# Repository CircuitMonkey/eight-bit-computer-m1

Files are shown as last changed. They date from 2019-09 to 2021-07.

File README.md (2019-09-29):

# eight-bit-computer-m1
Surface Mount Technology (SMT) implementation of Ben Eater's 8-bit Computer

The "M1" project is a Surface Mount Technology (SMT) implementation of [Ben Eater's 8-bit computer project](https://eater.net/8bit) as a compact and modular kit designed in Autodesk Eagle.   If you don't want to mess with SMT or Eagle, Ben has made his kit PCB available in KiCAD already,  or consider purchasing his kit.

For this implementation, I have re-entered all of the design files and created new suirface-mount library components into Eagle, by hand.  Therefore there are likely to be a few errors or unexpected differences encountered. Your feedback would be much appreciated.

Circuit Monkey is not affiliated with Ben Eater. However, if you appreciate this or Ben's project, please consider supporting Ben's work directly and financially using any one of the methods listed on his website.

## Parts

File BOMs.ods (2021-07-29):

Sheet: center-plane-rev-a
Part | Value | Package | Description | Price | Have | Buy
FAB | PCB Fab |  |  | $15.00
RL1 | 1K | 0603-RES | Resistor | $0.05
RL2 | 1K | 0603-RES | Resistor | $0.05
R0 | 1K | 0603-RES | Resistor | $0.05
R1 | 1K | 0603-RES | Resistor | $0.05
R2 | 1K | 0603-RES | Resistor | $0.05
R3 | 1K | 0603-RES | Resistor | $0.05
R4 | 1K | 0603-RES | Resistor | $0.05
R5 | 1K | 0603-RES | Resistor | $0.05
R6 | 1K | 0603-RES | Resistor | $0.05
R7 | 1K | 0603-RES | Resistor | $0.05
R8 | 10K | 0603-RES | Resistor | $0.05
R9 | 10K | 0603-RES | Resistor | $0.05
R10 | 10K | 0603-RES | Resistor | $0.05
R11 | 10K | 0603-RES | Resistor | $0.05
R12 | 10K | 0603-RES | Resistor | $0.05
R13 | 10K | 0603-RES | Resistor | $0.05
R14 | 10K | 0603-RES | Resistor | $0.05
R15 | 10K | 0603-RES | Resistor | $0.05
0 | BLUE | SMD_0603 | LED SMT | $0.15 |  |  | Wurth | 150060BS75000
1 | BLUE | SMD_0603 | LED SMT | $0.15 |  |  | Wurth | 150060BS75000
2 | BLUE | SMD_0603 | LED SMT | $0.15 |  |  | Wurth | 150060BS75000
3 | BLUE | SMD_0603 | LED SMT | $0.15 |  |  | Wurth | 150060BS75000
4 | BLUE | SMD_0603 | LED SMT | $0.15 |  |  | Wurth | 150060BS75000
5 | BLUE | SMD_0603 | LED SMT | $0.15 |  |  | Wurth | 150060BS75000
6 | BLUE | SMD_0603 | LED SMT | $0.15 |  |  | Wurth | 150060BS75000
7 | BLUE | SMD_0603 | LED SMT | $0.15 |  |  | Wurth | 150060BS75000
PLD1 | BLUE | SMD_0603 | LED SMT | $0.15 |  |  | Wurth | 150060BS75000
PLD2 | BLUE | SMD_0603 | LED SMT | $0.15 |  |  | Wurth | 150060BS75000
ALU | M1-ALU-BUS | ALU | ALU – PCB
CLK | M1-CLOCK-BUS | CLOCK | Clock - Bus Side – PCB | $7.57
CTL | M1-CONTROL-BUS | CONTROL | Control Logic - PCB
RAM | M1-RAM-BUS | M1-RAM-BUS | M1 - RAM - Bus Side
MAR | M1-MAR-BUS | MAR | MAR – PCB
OUT | M1-REG-OUTPUT-BUS | OUTPUT | Output – PCB | $19.55
PC | M1-PROG-COUNTER-BUS | PC | PC -PCB | $6.30
A | M1-REG-A-BUS | REG-A | Register A – PCB | $9.45
B | M1-REG-B-BUS | REG-B | Register B – PCB | $9.21
IR | M1-REG-INSTR-BUS | REG-I | Register Inst. - PCB | $9.45
 |  |  | Parts Total: | $78.93

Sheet: output-rev-a
Part | Value | Package | Description | Price | Have | Buy | MFR | MPN
C2 | 0.1uF | 0603-CAP | Capacitor CAP | $0.10
C3 | 0.1uF | 0603-CAP | Capacitor CAP | $0.10
C4 | 0.1uF | 0603-CAP | Capacitor CAP | $0.10
C5 | 0.1uF | 0603-CAP | Capacitor CAP | $0.10
C6 | 0.1uF | 0603-CAP | Capacitor CAP | $0.10
CCT | 0.01uF | 0603-CAP | Capacitor CAP | $0.10
CTH | 0.01uF | 0603-CAP | Capacitor CAP | $0.10
R1 | 100K | 0603-RES | Resistor | $0.05
R2 | 1K | 0603-RES | Resistor | $0.05
R3 | 1K | 0603-RES | Resistor | $0.05
R4 | 1K | 0603-RES | Resistor | $0.05
R5 | 1K | 0603-RES | Resistor | $0.05
R6 | 1K | 0603-RES | Resistor | $0.05
R7 | 1K | 0603-RES | Resistor | $0.05
R8 | 1K | 0603-RES | Resistor | $0.05
R9 | 1K | 0603-RES | Resistor | $0.05
R10 | 1K | 0603-RES | Resistor | $0.05
LED0 | BLUE | AVAGO-HDSM-283B-7SEG | Seven Segment LED Display | $2.70 |  |  | Avago | HDSM-283B
LED1 | BLUE | AVAGO-HDSM-283B-7SEG | Seven Segment LED Display | $2.70 |  |  | Avago | HDSM-283B
LED2 | BLUE | AVAGO-HDSM-283B-7SEG | Seven Segment LED Display | $2.70 |  |  | Avago | HDSM-283B
LED3 | BLUE | AVAGO-HDSM-283B-7SEG | Seven Segment LED Display | $2.70 |  |  | Avago | HDSM-283B
U1 | 555 | SOP08 | 555 Timer Chip | $0.50 |  |  | TI | NE555PSR
U2 | 74HCT109D | SO16 | Dual J-K Flip Flop Pos. Edge | $0.50 |  |  |  | 74HCT109D
U3 | 74LS139AD | SO16 | Dual 2-line to 4-line Decoder/Demux | $0.75 |  |  |  | 74LS139AD
U4 | 74LS273NS | SO20 | Octal D-type Flip Flop | $0.85 |  |  |  | 74LS273NS
U5 | 74LS08 | SOP14 | Quad AND Gate | $0.55 |  |  |  | 74LS08D
U6 | 28C64 | SO28 | EEPROM 8K x 8 | $4.40 |  |  | Microchip | AT28C64B-15SU
 |  |  | Parts Total: | $19.55

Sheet: clock-rev-a
M1 – Clock |  |  |  | Rev.A
Part | Value | Package | Description | Price | HAVE | BUY | MFR | MPN | MPN2
FAB | Clock PCB |  | PCB | $2.00
C1 | 0.01uF | 0603-CAP | Capacitor | $0.10
C2 | 1.0uF | 0603-CAP | Capacitor | $0.20
C3 | 0.01uF | 0603-CAP | Capacitor | $0.10
C4 | 0.01uF | 0603-CAP | Capacitor | $0.10
C5 | 0.01uF | 0603-CAP | Capacitor | $0.10
CU4 | 0.01uF | 0603-CAP | Capacitor | $0.10
CU5 | 0.01uF | 0603-CAP | Capacitor | $0.10
R1 | 1K | 0603-RES | Resistor | $0.05
R2 | 1K | 0603-RES | Resistor | $0.05
R3 | 1K | 0603-RES | Resistor | $0.05
R4 | 1K | 0603-RES | Resistor | $0.05
R5 | 1K | 0603-RES | Resistor | $0.05
R6 | 1K | 0603-RES | Resistor | $0.05
R7 | 1K | 0603-RES | Resistor | $0.05
.CLK. | BLUE | SMD_0603 | LED SMT | $0.15
F | 1M | TRIM_BOURNS_TC33X | Potentiometer | $0.27 |  | Mouser | Bourns | TC33X-2-105
MODE |  | CK_JS102011JCQN | Slide Switch - SPDT | $0.70 |  |  | CK Switch | JS102011JCQN
STEP | MOM (OFF)-ON | SWITCH-0635-2P-SMD | Tactile Push Switch | $0.70 |  |  | CK Switch | PTS635S*SMTR | Pololu #1400
U1 | 555 | SOP08 | Timer Chip | $0.30 |  | Mouser | TI | NE555PSR
U2 | 555 | SOP08 | Timer Chip | $0.30 |  | Mouser | TI | NE555PSR
U3 | 555 | SOP08 | Timer Chip | $0.30 |  | Mouser | TI | NE555PSR
U4 | 74LS08 | SOP14 | 7408 Quad AND | $0.55 |  | Mouser |  | 74LS08D
U5 | 74LS32 | SOP14 | 7432 Quad XOR | $0.55 |  | Mouser |  | 74LS32D
U6 | 74LS04 | SOP14 | Hex Inverter | $0.60 |  | Mouser |  | 74LS04D
 |  |  | Parts Total: | $7.57

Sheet: register-a
M1-Register-A
Part | Value | Device | Package | Description | Cost | Have | Buy
FAB |  |  |  |  | $3.50
C1 | 0.1uF | CAPACITOR0603 | 0603-CAP | Capacitor CAP | $0.10
C2 | 0.1uF | CAPACITOR0603 | 0603-CAP | Capacitor CAP | $0.10
C3 | 0.1uF | CAPACITOR0603 | 0603-CAP | Capacitor CAP | $0.10
R0 | 1K | RESISTOR0603 | 0603-RES | Resistor | $0.05
R1 | 1K | RESISTOR0603 | 0603-RES | Resistor | $0.05
R2 | 1K | RESISTOR0603 | 0603-RES | Resistor | $0.05
R3 | 1K | RESISTOR0603 | 0603-RES | Resistor | $0.05
R4 | 1K | RESISTOR0603 | 0603-RES | Resistor | $0.05
R5 | 1K | RESISTOR0603 | 0603-RES | Resistor | $0.05
R6 | 1K | RESISTOR0603 | 0603-RES | Resistor | $0.05
R7 | 1K | RESISTOR0603 | 0603-RES | Resistor | $0.05
D.0 | BLUE | SMT0603 | SMD_0603 | LED SMT | $0.15
D.1 | BLUE | SMT0603 | SMD_0603 | LED SMT | $0.15
D.2 | BLUE | SMT0603 | SMD_0603 | LED SMT | $0.15
D.3 | BLUE | SMT0603 | SMD_0603 | LED SMT | $0.15
D.4 | BLUE | SMT0603 | SMD_0603 | LED SMT | $0.15
D.5 | BLUE | SMT0603 | SMD_0603 | LED SMT | $0.15
D.6 | BLUE | SMT0603 | SMD_0603 | LED SMT | $0.15
D.7 | BLUE | SMT0603 | SMD_0603 | LED SMT | $0.15
U1 | 74LS245NS | 74LS245NS | SO20 | 74245 Octal Transceiver | $0.95
U2 | 74LS173AD | 74LS173AD | SO16 | 74*173 Logic | $1.55
U3 | 74LS173AD | 74LS173AD | SO16 | 74*173 Logic | $1.55
 |  |  |  | Parts Total: | $9.45

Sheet: register-b
M1-Register-B
Part | Value | Device | Package | Description | Cost | Have | Buy
FAB |  |  |  | PCB Fab | $3.50
C1 | 0.1uF | CAPACITOR0603 | 0603-CAP | Capacitor CAP | $0.10
C2 | 0.1uF | CAPACITOR0603 | 0603-CAP | Capacitor CAP | $0.10
C3 | 0.1uF | CAPACITOR0603 | 0603-CAP | Capacitor CAP | $0.10
R0 | 1K | RESISTOR0603 | 0603-RES | Resistor | $0.05
R1 | 1K | RESISTOR0603 | 0603-RES | Resistor | $0.05
R2 | 1K | RESISTOR0603 | 0603-RES | Resistor | $0.05
R3 | 1K | RESISTOR0603 | 0603-RES | Resistor | $0.05
R4 | 1K | RESISTOR0603 | 0603-RES | Resistor | $0.05
R5 | 1K | RESISTOR0603 | 0603-RES | Resistor | $0.05
R6 | 1K | RESISTOR0603 | 0603-RES | Resistor | $0.05
R7 | 1K | RESISTOR0603 | 0603-RES | Resistor | $0.05
D.0 | BLUE | SMT0603 | SMD_0603 | LED SMT | $0.12
D.1 | BLUE | SMT0603 | SMD_0603 | LED SMT | $0.12
D.2 | BLUE | SMT0603 | SMD_0603 | LED SMT | $0.12
D.3 | BLUE | SMT0603 | SMD_0603 | LED SMT | $0.12
D.4 | BLUE | SMT0603 | SMD_0603 | LED SMT | $0.12
D.5 | BLUE | SMT0603 | SMD_0603 | LED SMT | $0.12
D.6 | BLUE | SMT0603 | SMD_0603 | LED SMT | $0.12
D.7 | BLUE | SMT0603 | SMD_0603 | LED SMT | $0.12
U1 | 74LS245NS | 74LS245NS | SO20 | 74245 Octal Transceiver | $0.95
U2 | 74LS173AD | 74LS173AD | SO16 | 74*173 Logic | $1.55
U3 | 74LS173AD | 74LS173AD | SO16 | 74*173 Logic | $1.55
 |  |  |  | Parts Total: | $9.21

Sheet: program-counter
M1-Program-Counter
Part | Value | Device | Package | Description | Cost | Have | Buy
FAB |  |  |  | PCB Fab | $3.50
C1 | 0.1uF | CAPACITOR0603 | 0603-CAP | Capacitor CAP | $0.10
C2 | 0.1uF | CAPACITOR0603 | 0603-CAP | Capacitor CAP | $0.10
R0 | 1K | RESISTOR0603 | 0603-RES | Resistor | $0.05
R1 | 1K | RESISTOR0603 | 0603-RES | Resistor | $0.05
R2 | 1K | RESISTOR0603 | 0603-RES | Resistor | $0.05
R3 | 1K | RESISTOR0603 | 0603-RES | Resistor | $0.05
PC0 | GREEN | SMT0603 | SMD_0603 | LED SMT | $0.15
PC1 | GREEN | SMT0603 | SMD_0603 | LED SMT | $0.15
PC2 | GREEN | SMT0603 | SMD_0603 | LED SMT | $0.15
PC3 | GREEN | SMT0603 | SMD_0603 | LED SMT | $0.15
U1 | 74LS245NS | 74LS245NS | SO20 | 74245 Octal Transceiver | $0.95
U2 | 74LS161AD | 74LS161AD | SO16 | Synchronous 4-bit Counter | $0.85
 |  |  |  | Parts Total: | $6.30

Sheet: register-i
M1-Instruction-Register
Part | Value | Device | Package | Description | Cost | Have | Buy
FAB |  |  |  | PCB FAB | $3.50
C1 |  | CAPACITOR0603 | 0603-CAP | Capacitor CAP | $0.10
C2 |  | CAPACITOR0603 | 0603-CAP | Capacitor CAP | $0.10
C3 |  | CAPACITOR0603 | 0603-CAP | Capacitor CAP | $0.10
R0 | 1K | RESISTOR0603 | 0603-RES | Resistor | $0.05
R1 | 1K | RESISTOR0603 | 0603-RES | Resistor | $0.05
R2 | 1K | RESISTOR0603 | 0603-RES | Resistor | $0.05
R3 | 1K | RESISTOR0603 | 0603-RES | Resistor | $0.05
R4 | 1K | RESISTOR0603 | 0603-RES | Resistor | $0.05
R5 | 1K | RESISTOR0603 | 0603-RES | Resistor | $0.05
R6 | 1K | RESISTOR0603 | 0603-RES | Resistor | $0.05
R7 | 1K | RESISTOR0603 | 0603-RES | Resistor | $0.05
D.0 | BLUE | SMT0603 | SMD_0603 | LED SMT | $0.15
D.1 | BLUE | SMT0603 | SMD_0603 | LED SMT | $0.15
D.2 | BLUE | SMT0603 | SMD_0603 | LED SMT | $0.15
D.3 | BLUE | SMT0603 | SMD_0603 | LED SMT | $0.15
D.4 | BLUE | SMT0603 | SMD_0603 | LED SMT | $0.15
D.5 | BLUE | SMT0603 | SMD_0603 | LED SMT | $0.15
D.6 | BLUE | SMT0603 | SMD_0603 | LED SMT | $0.15
D.7 | BLUE | SMT0603 | SMD_0603 | LED SMT | $0.15
U1 | 74LS245NS | 74LS245NS | SO20 | 74245 Octal Transceiver | $0.95
U2 | 74LS173AD | 74LS173AD | SO16 | 74*173 Logic | $1.55
U3 | 74LS173AD | 74LS173AD | SO16 | 74*173 Logic | $1.55
 |  |  |  | Parts Total: | $9.45

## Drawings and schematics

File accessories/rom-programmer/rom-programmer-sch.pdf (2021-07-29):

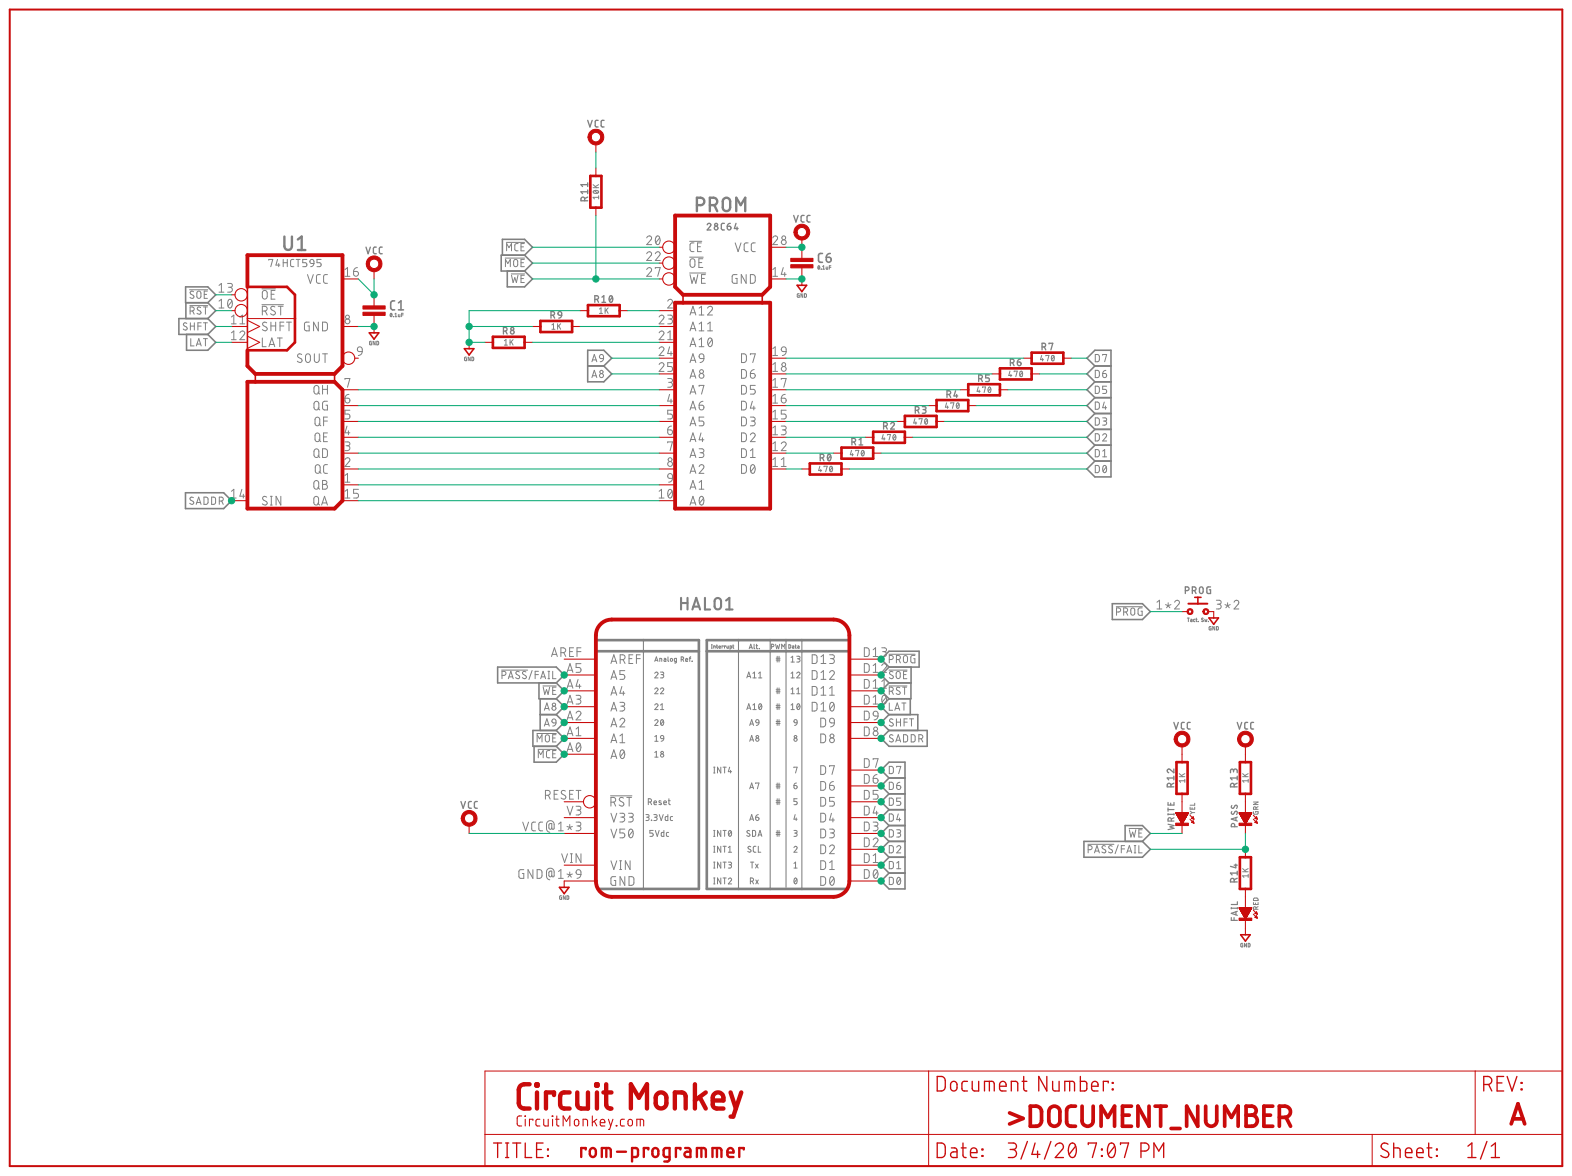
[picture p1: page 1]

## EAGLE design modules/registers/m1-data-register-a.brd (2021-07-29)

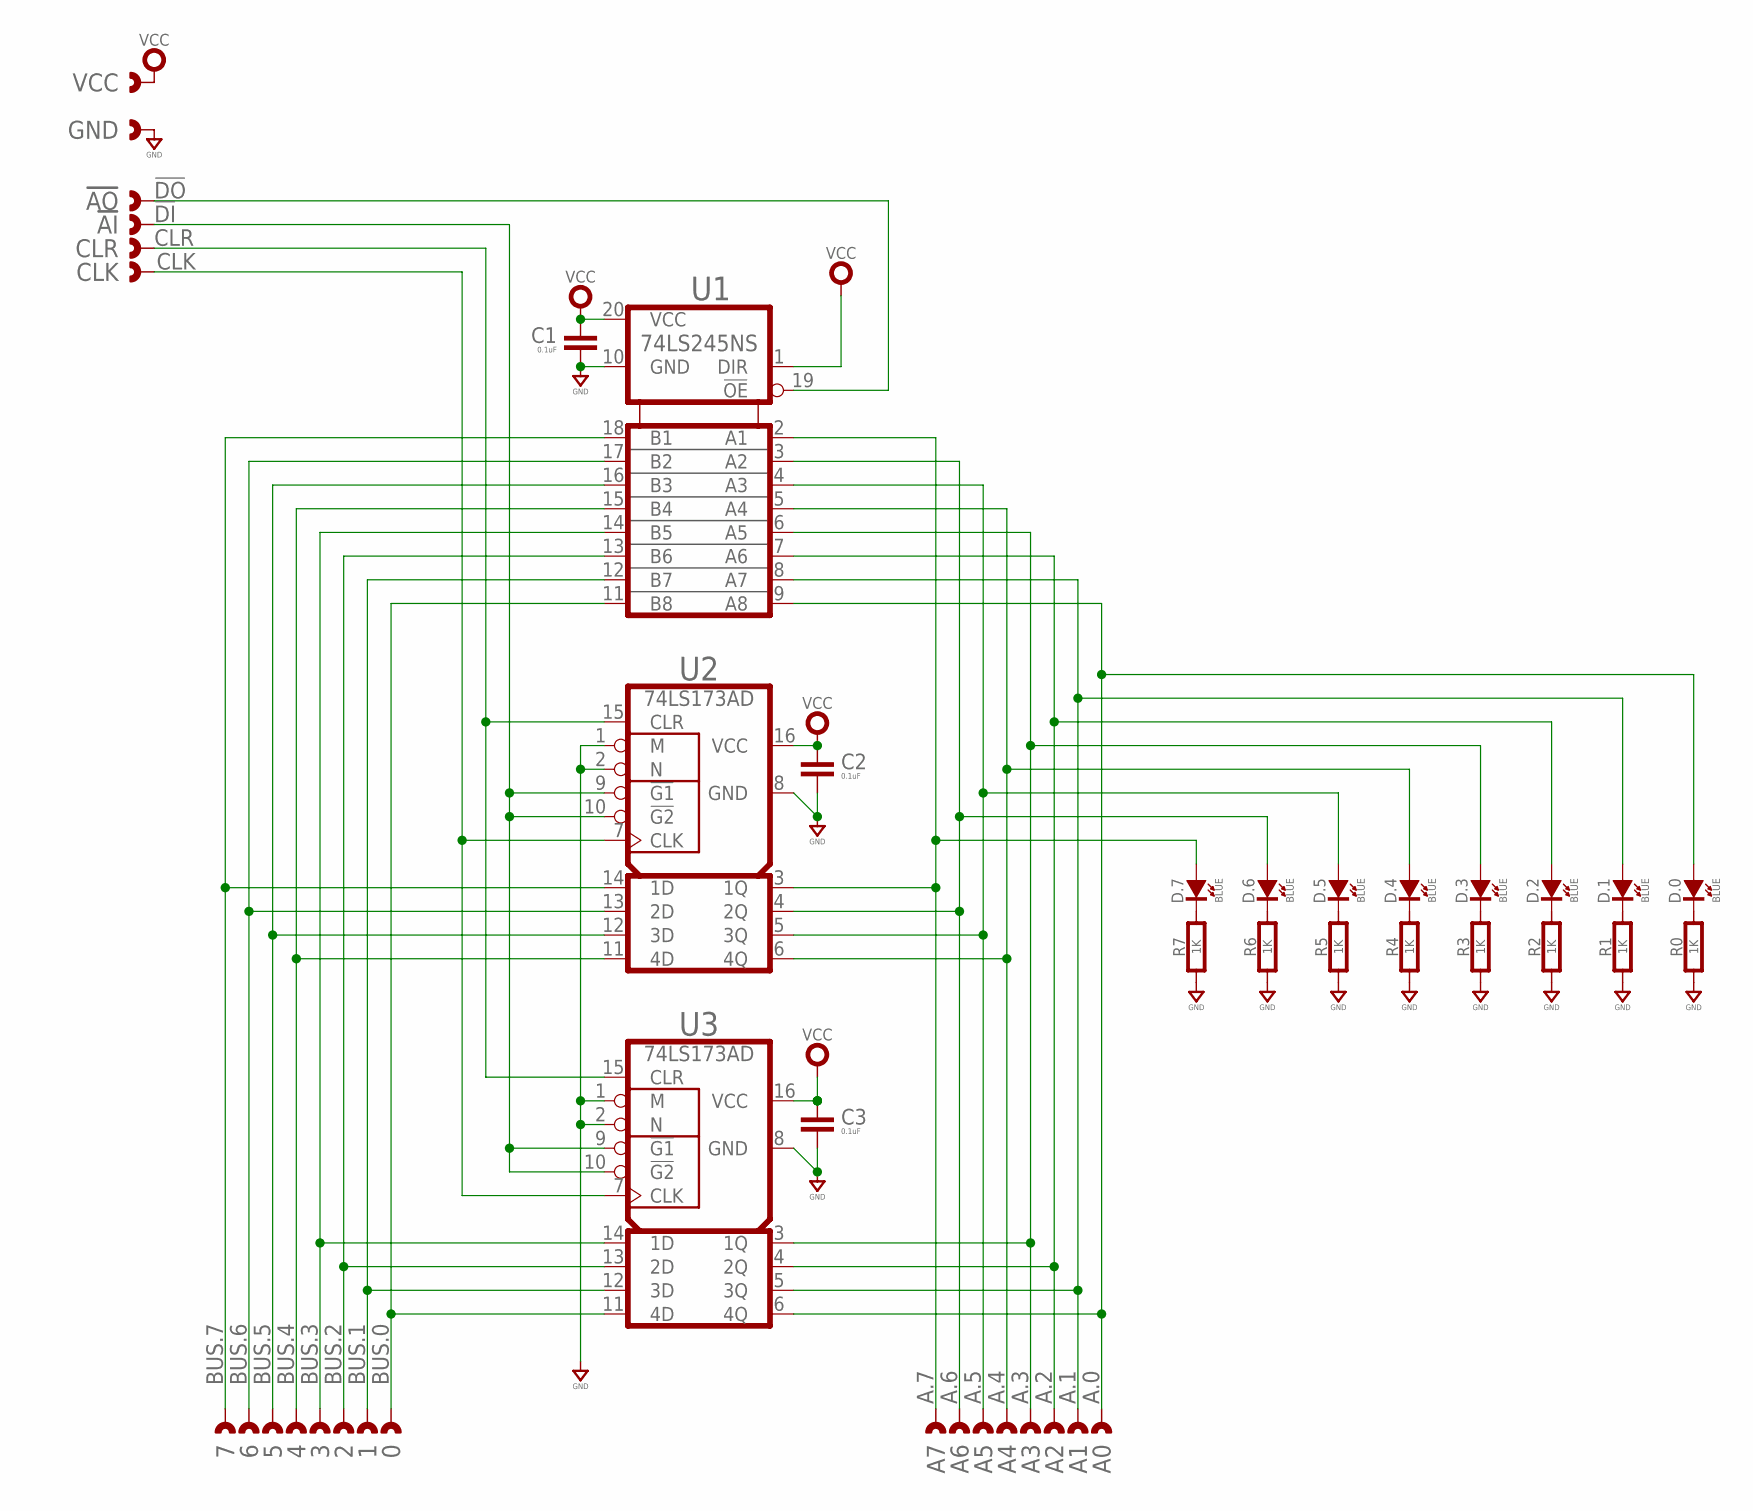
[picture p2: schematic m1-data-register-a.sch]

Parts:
0, 1, 2, 3, 4, 5, 6, 7: CAST-01X1; CAST01-2.54MM
!AI: CAST-01X1; CAST01-2.54MM
!AO: CAST-01X1; CAST01-2.54MM
A0, A1, A2, A3, A4, A5, A6, A7: CAST-01X1; CAST01-2.54MM
C1, C2, C3: 0.1uF; 0603-CAP
CLK: CAST-01X1; CAST01-2.54MM
CLR: CAST-01X1; CAST01-2.54MM
D.0, D.1, D.2, D.3, D.4, D.5, D.6, D.7: BLUE; SMD_0603
GND: CAST-01X1; CAST01-2.54MM
R0, R1, R2, R3, R4, R5, R6, R7: 1K; 0603-RES
U1: 74LS245NS; SO20
U2, U3: 74LS173AD; SO16
VCC: CAST-01X1; CAST01-2.54MM

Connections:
!DI: !AI.1, U2.9 (!G1), U2.10 (!G2), U3.9 (!G1), U3.10 (!G2)
!DO: !AO.1, U1.19 (!OE)
A.0: A0.1, D.0.A, U1.9 (A8), U3.6 (4Q)
A.1: A1.1, D.1.A, U1.8 (A7), U3.5 (3Q)
A.2: A2.1, D.2.A, U1.7 (A6), U3.4 (2Q)
A.3: A3.1, D.3.A, U1.6 (A5), U3.3 (1Q)
A.4: A4.1, D.4.A, U1.5 (A4), U2.6 (4Q)
A.5: A5.1, D.5.A, U1.4 (A3), U2.5 (3Q)
A.6: A6.1, D.6.A, U1.3 (A2), U2.4 (2Q)
A.7: A7.1, D.7.A, U1.2 (A1), U2.3 (1Q)
BUS.0: 0.1, U1.11 (B8), U3.11 (4D)
BUS.1: 1.1, U1.12 (B7), U3.12 (3D)
BUS.2: 2.1, U1.13 (B6), U3.13 (2D)
BUS.3: 3.1, U1.14 (B5), U3.14 (1D)
BUS.4: 4.1, U1.15 (B4), U2.11 (4D)
BUS.5: 5.1, U1.16 (B3), U2.12 (3D)
BUS.6: 6.1, U1.17 (B2), U2.13 (2D)
BUS.7: 7.1, U1.18 (B1), U2.14 (1D)
CLK: CLK.1, U2.7 (CLK), U3.7 (CLK)
CLR: CLR.1, U2.15 (CLR), U3.15 (CLR)
GND: C1.2, C2.2, C3.2, GND.1, R0.1, R1.1, R2.1, R3.1, R4.1, R5.1, R6.1, R7.1, U1.10 (GND), U2.1 (M), U2.2 (N), U2.8 (GND), U3.1 (M), U3.2 (N), U3.8 (GND)
unnamed: D.0.K (C), R0.2
unnamed: D.1.K (C), R1.2
unnamed: D.2.K (C), R2.2
unnamed: D.3.K (C), R3.2
unnamed: D.4.K (C), R4.2
unnamed: D.5.K (C), R5.2
unnamed: D.6.K (C), R6.2
unnamed: D.7.K (C), R7.2
VCC: C1.1, C2.1, C3.1, U1.1 (DIR), U1.20 (VCC), U2.16 (VCC), U3.16 (VCC), VCC.1

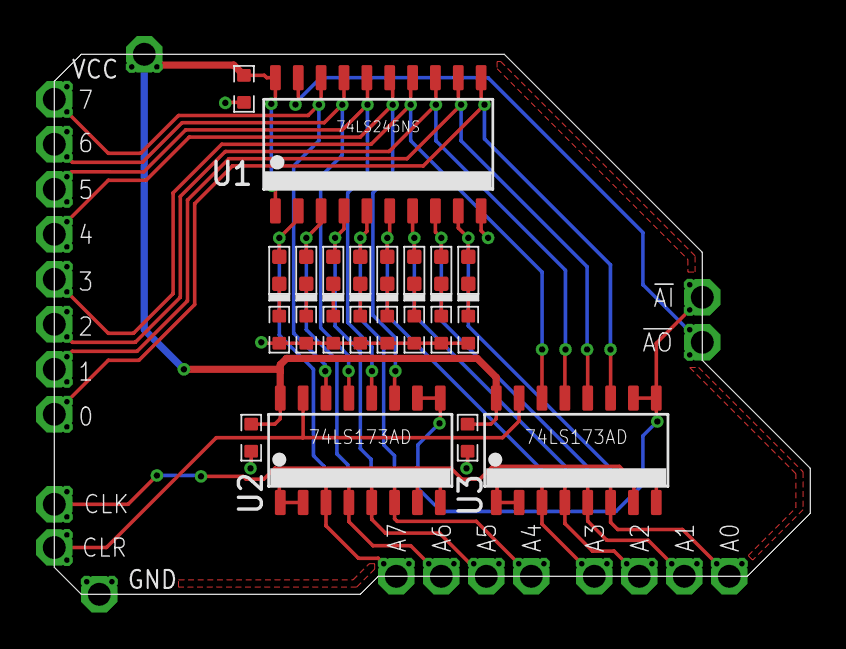
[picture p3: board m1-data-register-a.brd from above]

Board: 2 copper layers, 42.0 x 30.0 mm, 44 parts (0 on the bottom side), 30 nets.

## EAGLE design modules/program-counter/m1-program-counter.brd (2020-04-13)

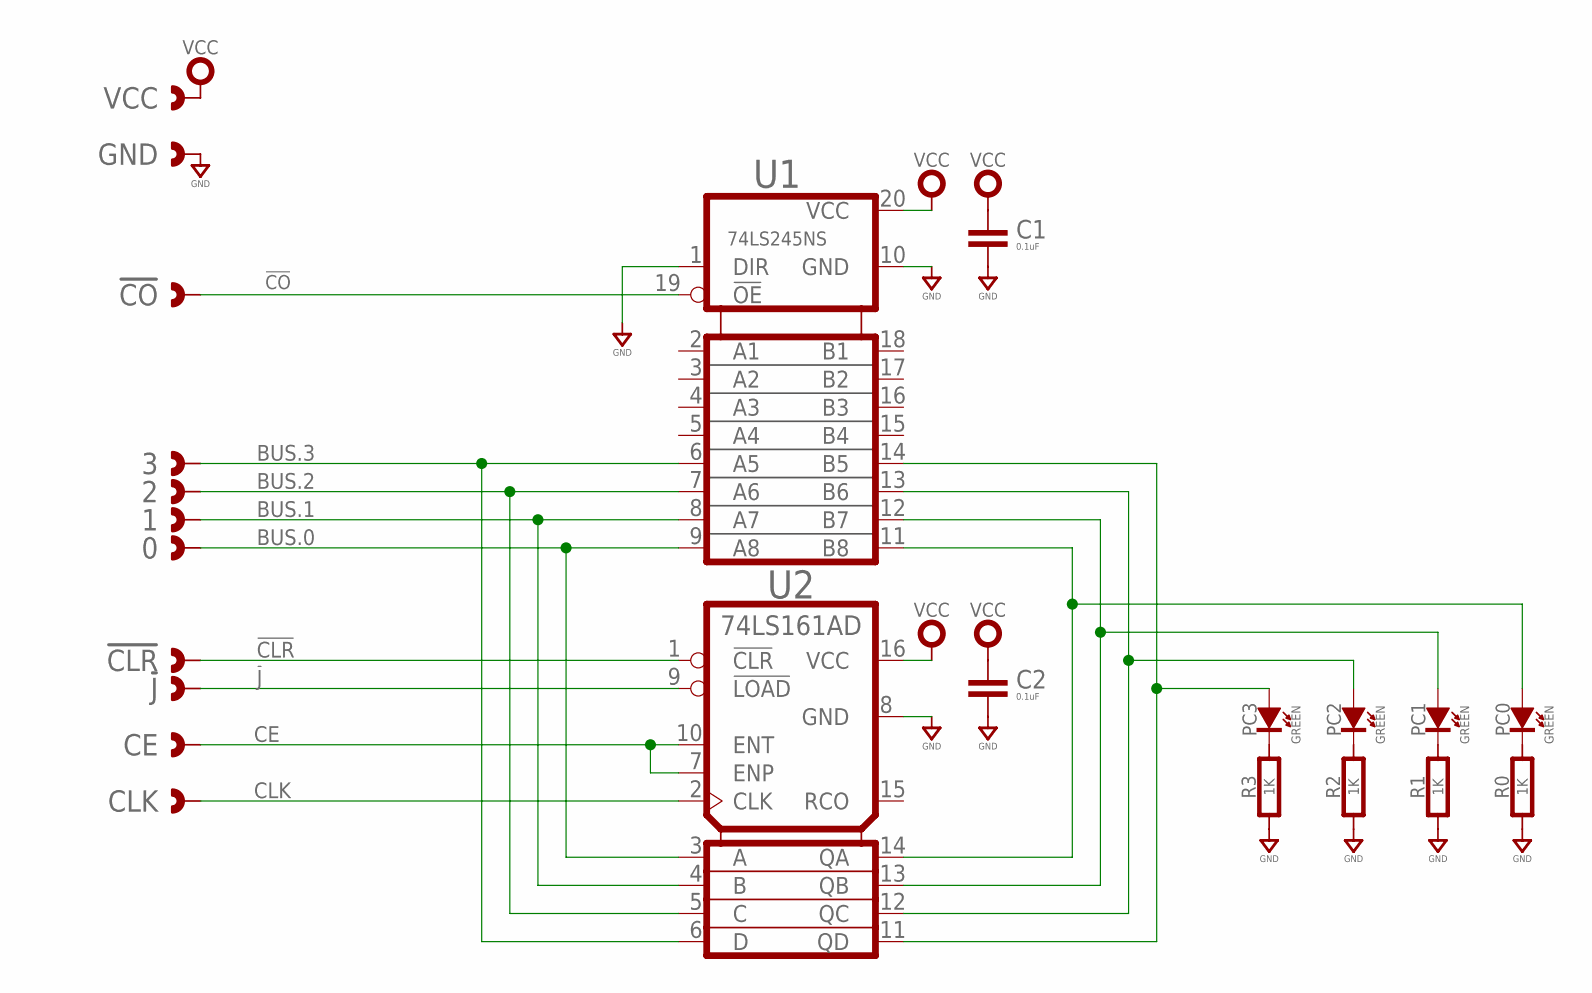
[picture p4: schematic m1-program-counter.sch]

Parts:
0, 1, 2, 3: CAST-01X1; CAST01-2.54MM
!CLR: CAST-01X1; CAST01-2.54MM
!CO: CAST-01X1; CAST01-2.54MM
!J: CAST-01X1; CAST01-2.54MM
C1, C2: 0.1uF; 0603-CAP
CE: CAST-01X1; CAST01-2.54MM
CLK: CAST-01X1; CAST01-2.54MM
GND: CAST-01X1; CAST01-2.54MM
PC0, PC1, PC2, PC3: GREEN; SMD_0603
R0, R1, R2, R3: 1K; 0603-RES
U1: 74LS245NS; SO20
U2: 74LS161AD; SO16
VCC: CAST-01X1; CAST01-2.54MM

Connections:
!CLR: !CLR.1, U2.1 (!CLR)
!CO: !CO.1, U1.19 (!OE)
!J: !J.1, U2.9 (!LOAD)
BUS.0: 0.1, U1.9 (A8), U2.3 (A)
BUS.1: 1.1, U1.8 (A7), U2.4 (B)
BUS.2: 2.1, U1.7 (A6), U2.5 (C)
BUS.3: 3.1, U1.6 (A5), U2.6 (D)
CE: CE.1, U2.7 (ENP), U2.10 (ENT)
CLK: CLK.1, U2.2 (CLK)
GND: C1.2, C2.2, GND.1, R0.1, R1.1, R2.1, R3.1, U1.1 (DIR), U1.10 (GND), U2.8 (GND)
unnamed: PC0.A, U1.11 (B8), U2.14 (QA)
unnamed: PC1.A, U1.12 (B7), U2.13 (QB)
unnamed: PC2.A, U1.13 (B6), U2.12 (QC)
unnamed: PC3.A, U1.14 (B5), U2.11 (QD)
unnamed: PC0.K (C), R0.2
unnamed: PC1.K (C), R1.2
unnamed: PC2.K (C), R2.2
unnamed: PC3.K (C), R3.2
VCC: C1.1, C2.1, U1.20 (VCC), U2.16 (VCC), VCC.1

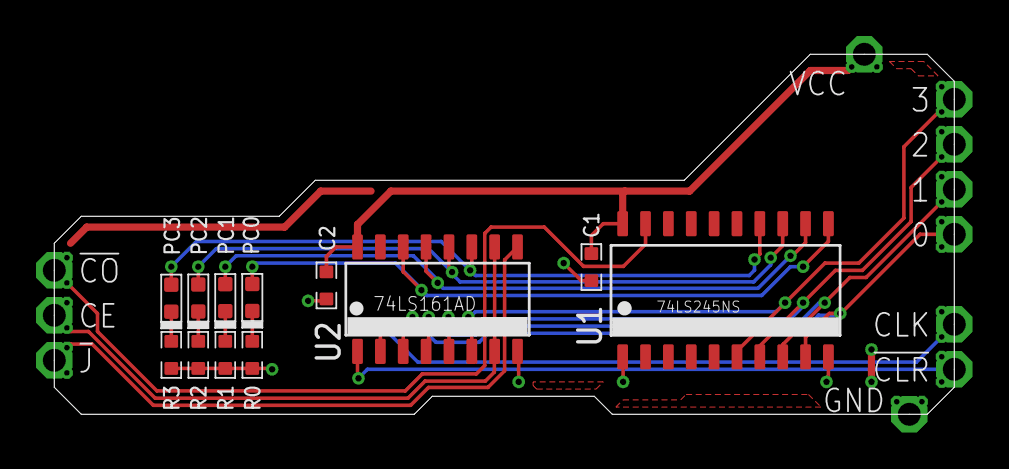
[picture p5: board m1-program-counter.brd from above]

Board: 2 copper layers, 50.0 x 20.0 mm, 23 parts (0 on the bottom side), 19 nets.

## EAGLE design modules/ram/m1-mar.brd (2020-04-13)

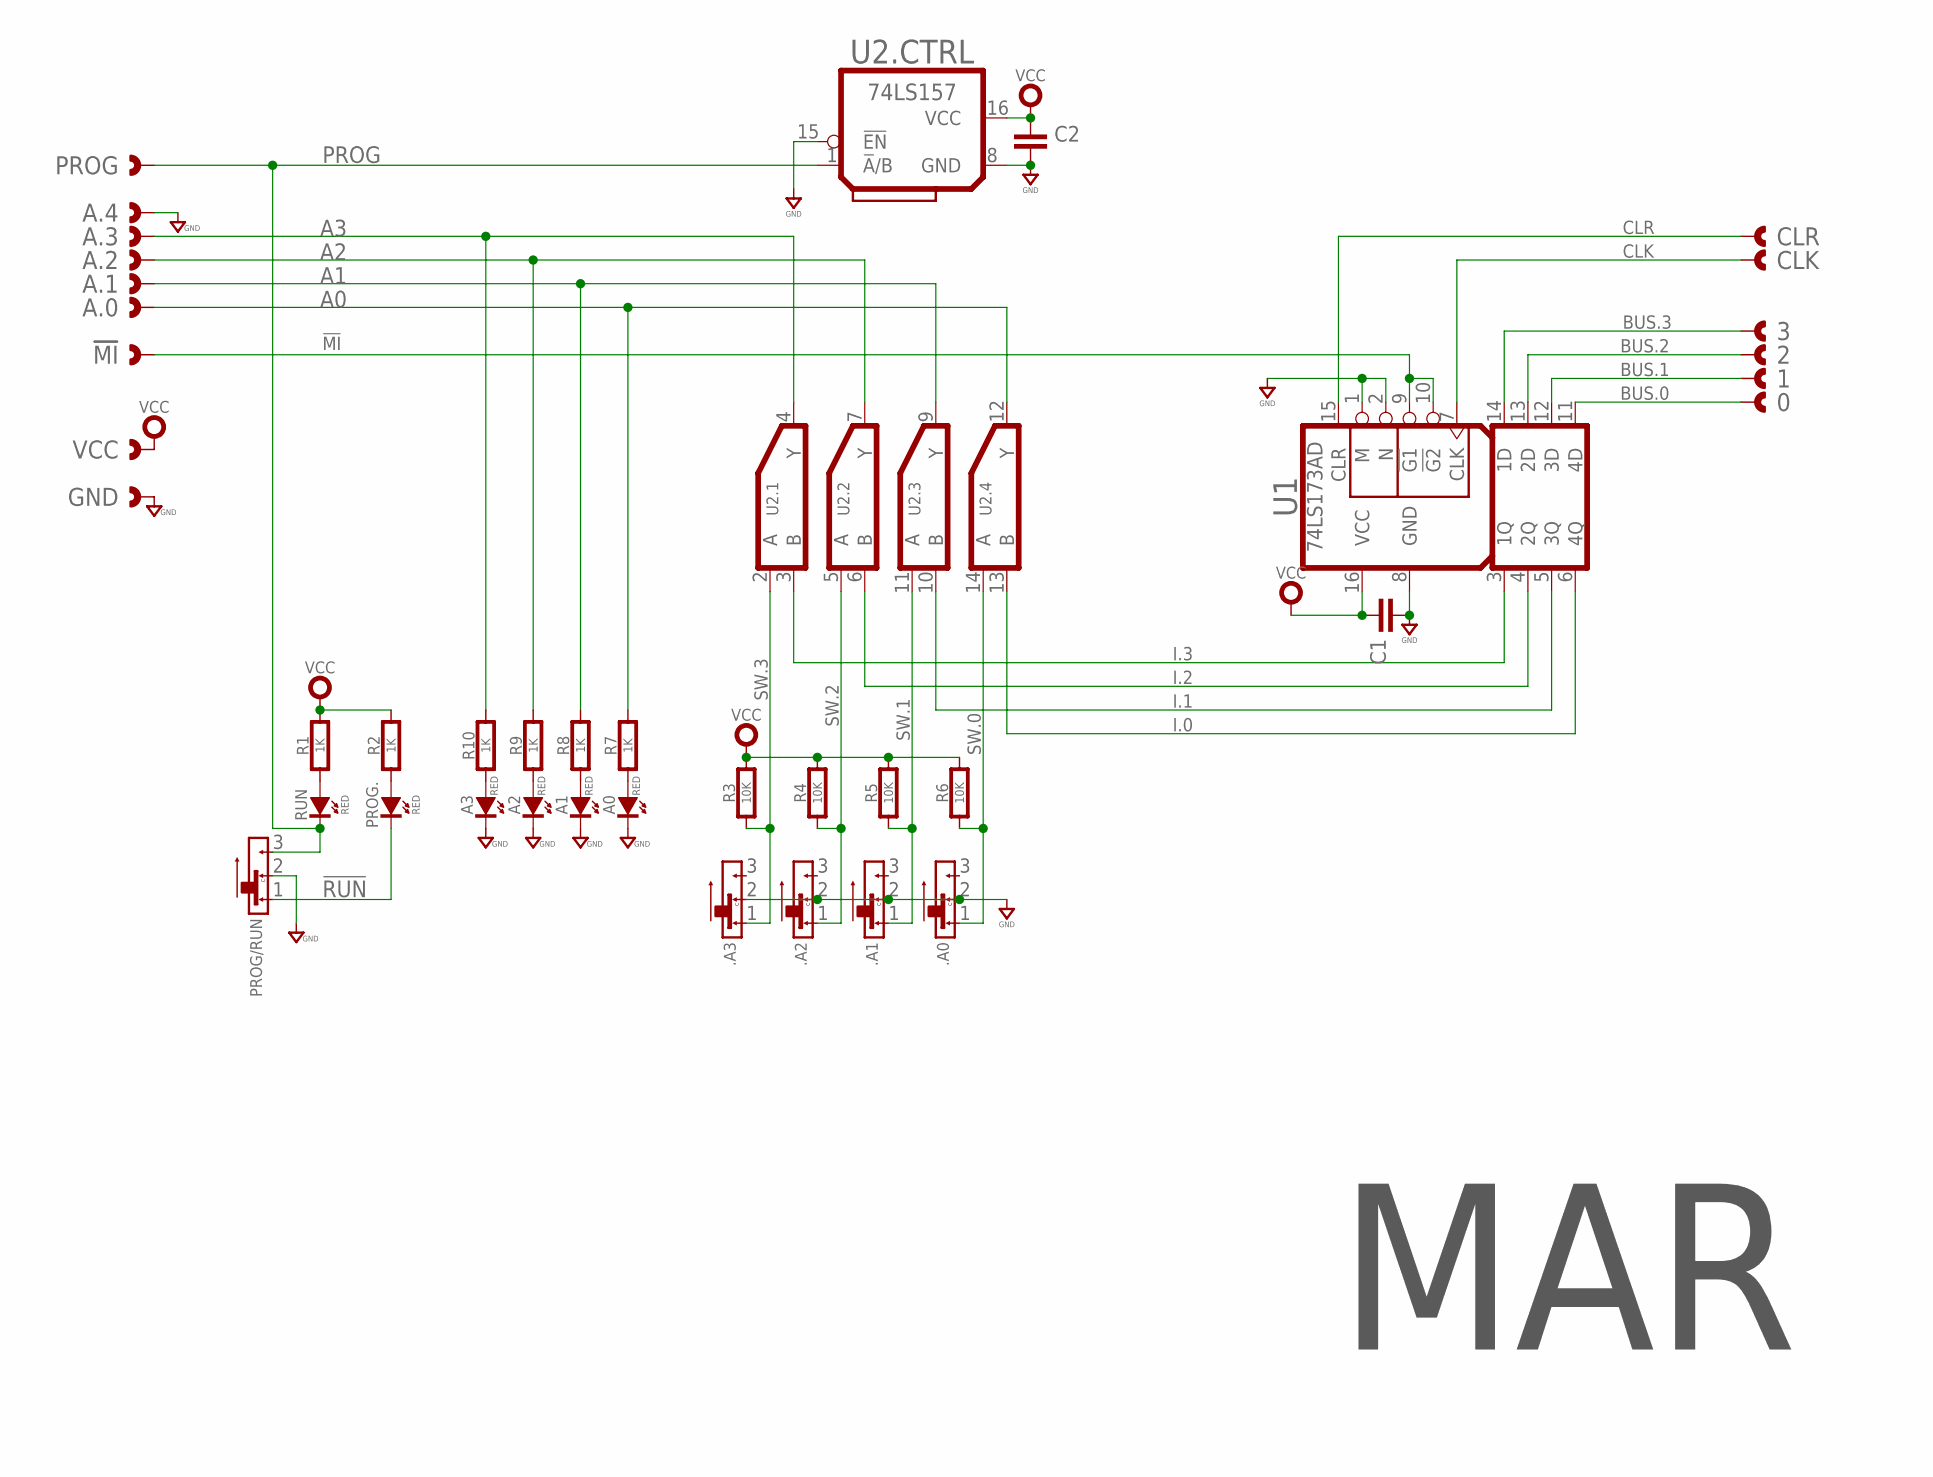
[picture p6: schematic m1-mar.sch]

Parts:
0, 1, 2, 3: CAST-01X1; CAST01-2.54MM
!MI: CAST-01X1; CAST01-2.54MM
.A0, .A1, .A2, .A3: SLIDE-SPDTJS102011JCQN; CK_JS102011JCQN
A0, A1, A2, A3: RED; SMD_0603
A.0, A.1, A.2, A.3, A.4: CAST-01X1; CAST01-2.54MM
C1, C2: CAPACITOR0603; 0603-CAP
CLK: CAST-01X1; CAST01-2.54MM
CLR: CAST-01X1; CAST01-2.54MM
GND: CAST-01X1; CAST01-2.54MM
PROG: CAST-01X1; CAST01-2.54MM
PROG.: RED; SMD_0603
PROG/RUN: SLIDE-SPDTJS102011JCQN; CK_JS102011JCQN
R1, R2, R7, R8, R9, R10: 1K; 0603-RES
R3, R4, R5, R6: 10K; 0603-RES
RUN: RED; SMD_0603
U1: 74LS173AD; SO16
U2: 74LS157; SO16
VCC: CAST-01X1; CAST01-2.54MM

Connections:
!MI: !MI.1, U1.9 (!G1), U1.10 (!G2)
!RUN: PROG..K (C), PROG/RUN.1
A0: A.0.1, R7.2, U2.12 (Y)
A1: A.1.1, R8.2, U2.9 (Y)
A2: A.2.1, R9.2, U2.7 (Y)
A3: A.3.1, R10.2, U2.4 (Y)
BUS.0: 0.1, U1.11 (4D)
BUS.1: 1.1, U1.12 (3D)
BUS.2: 2.1, U1.13 (2D)
BUS.3: 3.1, U1.14 (1D)
CLK: CLK.1, U1.7 (CLK)
CLR: CLR.1, U1.15 (CLR)
GND: .A0.2, .A1.2, .A2.2, .A3.2, A0.K (C), A1.K (C), A2.K (C), A3.K (C), A.4.1, C1.2, C2.2, GND.1, PROG/RUN.2, U1.1 (M), U1.2 (N), U1.8 (GND), U2.8 (GND), U2.15 (!EN)
I.0: U1.6 (4Q), U2.13 (B)
I.1: U1.5 (3Q), U2.10 (B)
I.2: U1.4 (2Q), U2.6 (B)
I.3: U1.3 (1Q), U2.3 (B)
unnamed: A0.A, R7.1
unnamed: R1.1, RUN.A
unnamed: PROG..A, R2.1
unnamed: A1.A, R8.1
unnamed: A2.A, R9.1
unnamed: A3.A, R10.1
PROG: PROG.1, PROG/RUN.3, RUN.K (C), U2.1 (!A!/B)
SW.0: .A0.1, R6.1, U2.14 (A)
SW.1: .A1.1, R5.1, U2.11 (A)
SW.2: .A2.1, R4.1, U2.5 (A)
SW.3: .A3.1, R3.1, U2.2 (A)
VCC: C1.1, C2.1, R1.2, R2.2, R3.2, R4.2, R5.2, R6.2, U1.16 (VCC), U2.16 (VCC), VCC.1

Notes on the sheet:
MAR

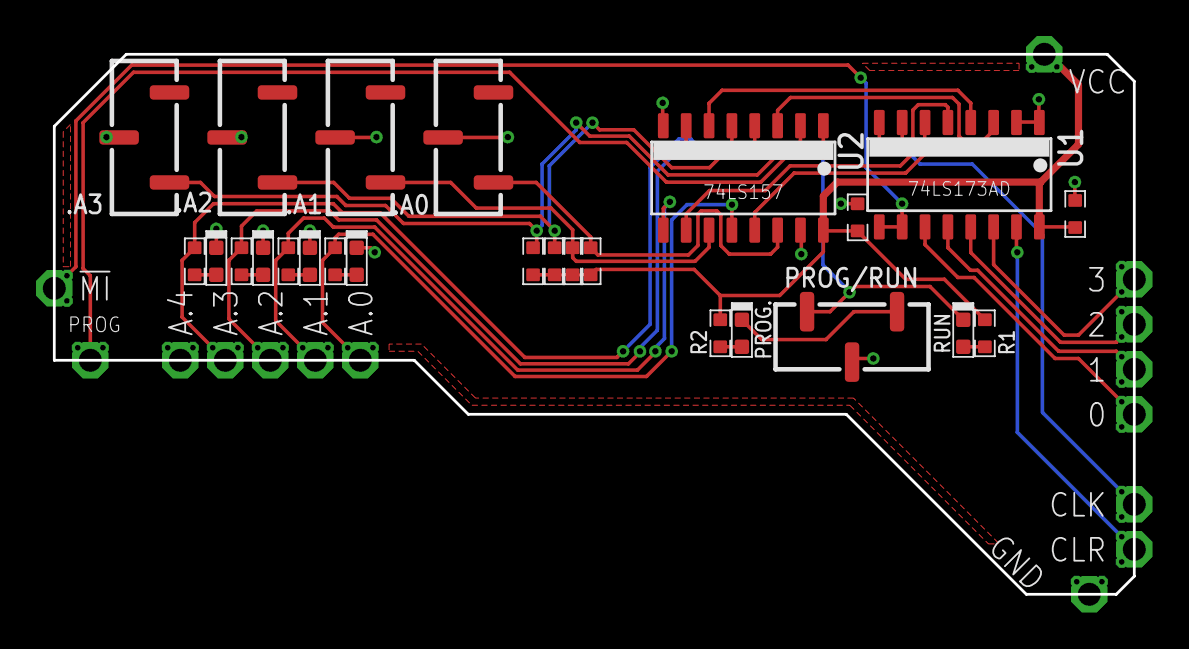
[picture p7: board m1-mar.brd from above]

Board: 2 copper layers, 60.0 x 30.0 mm, 40 parts (0 on the bottom side), 29 nets.

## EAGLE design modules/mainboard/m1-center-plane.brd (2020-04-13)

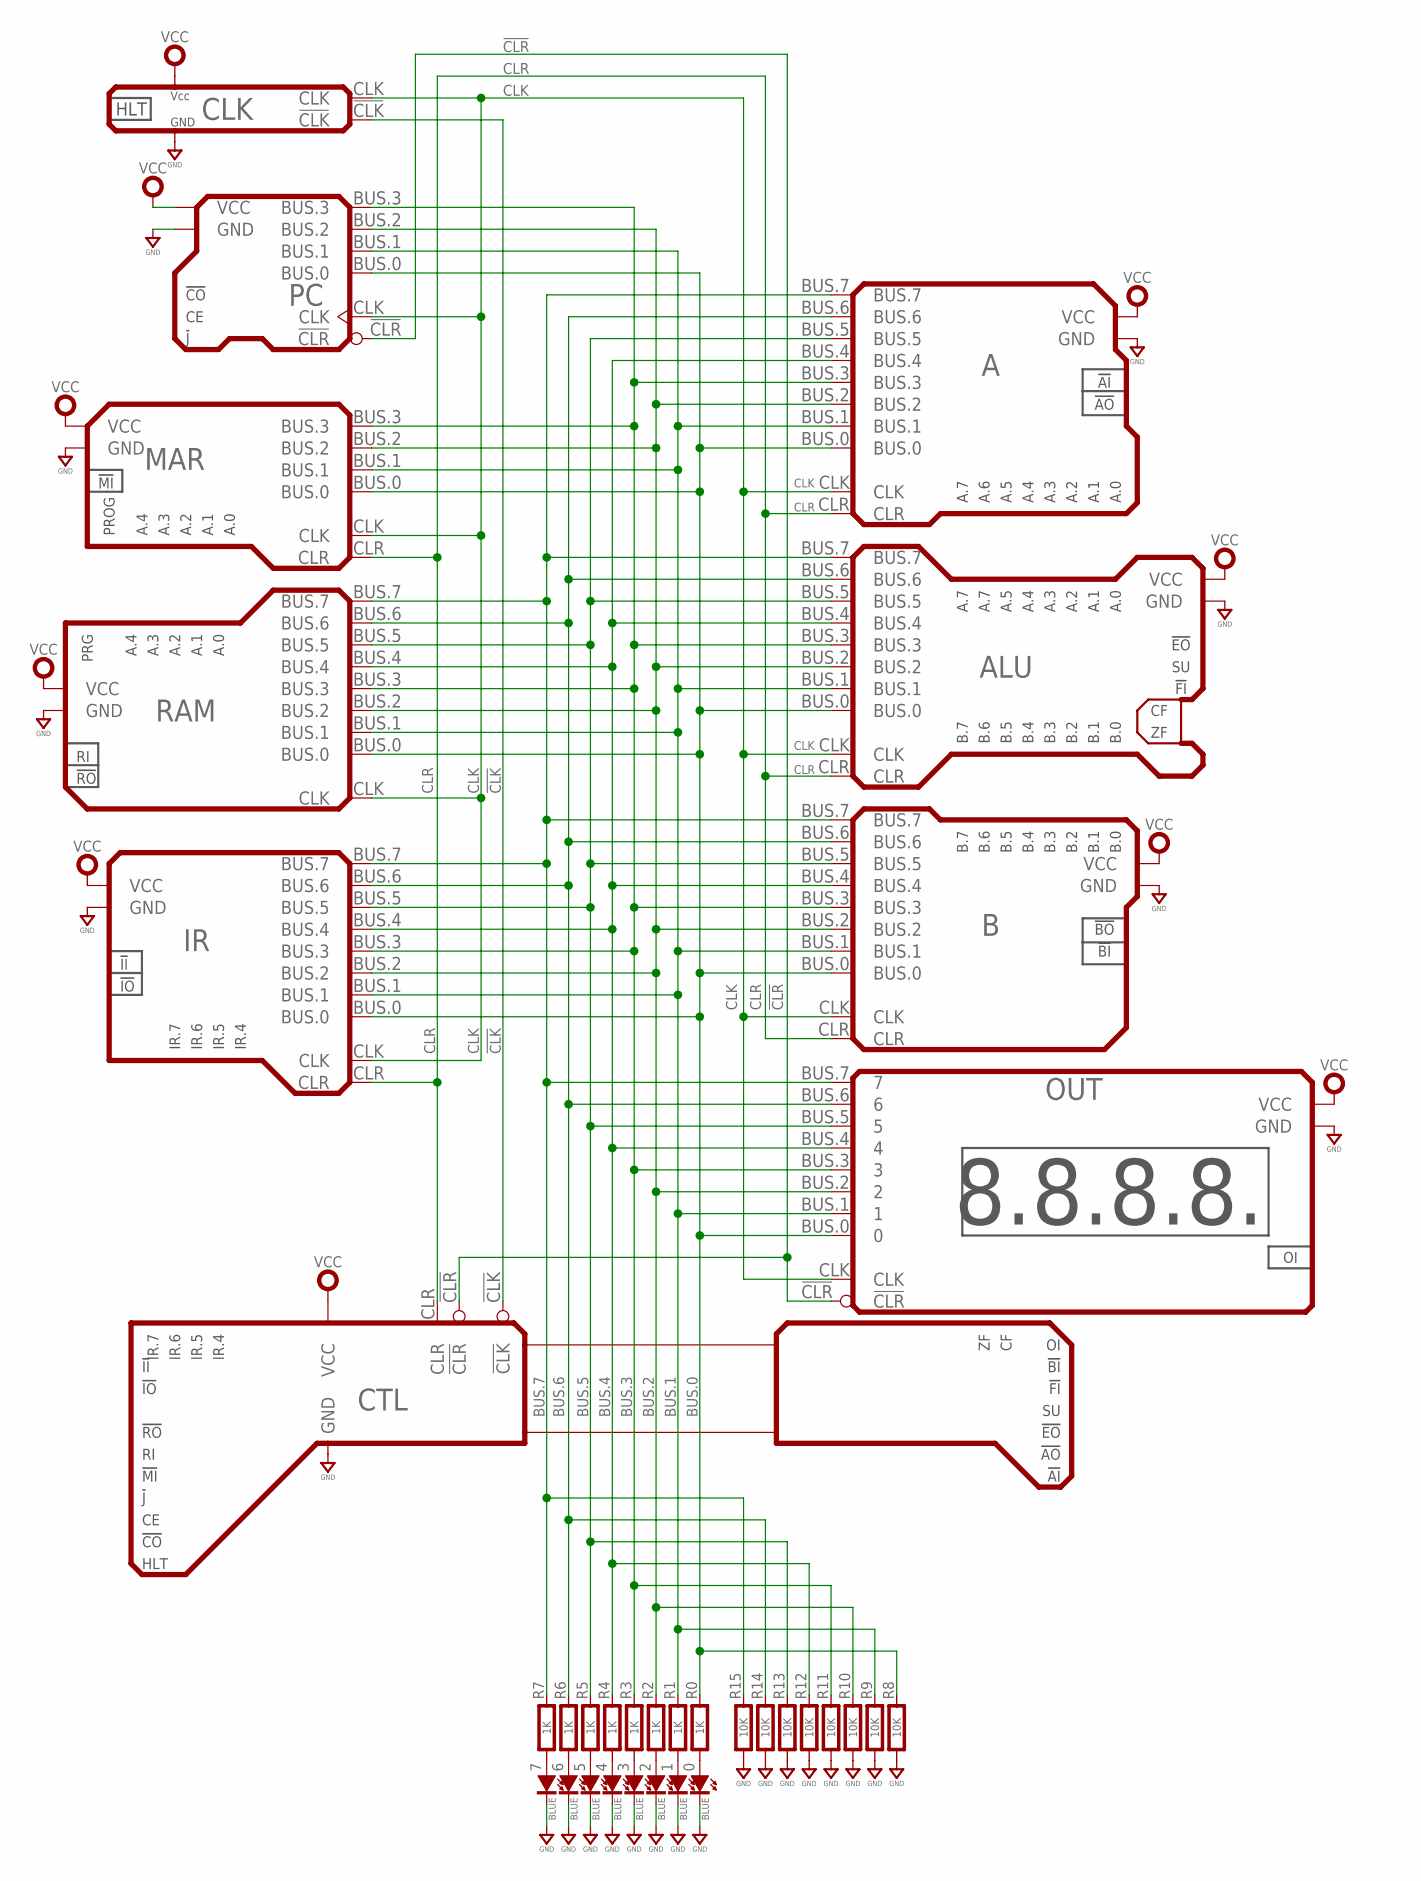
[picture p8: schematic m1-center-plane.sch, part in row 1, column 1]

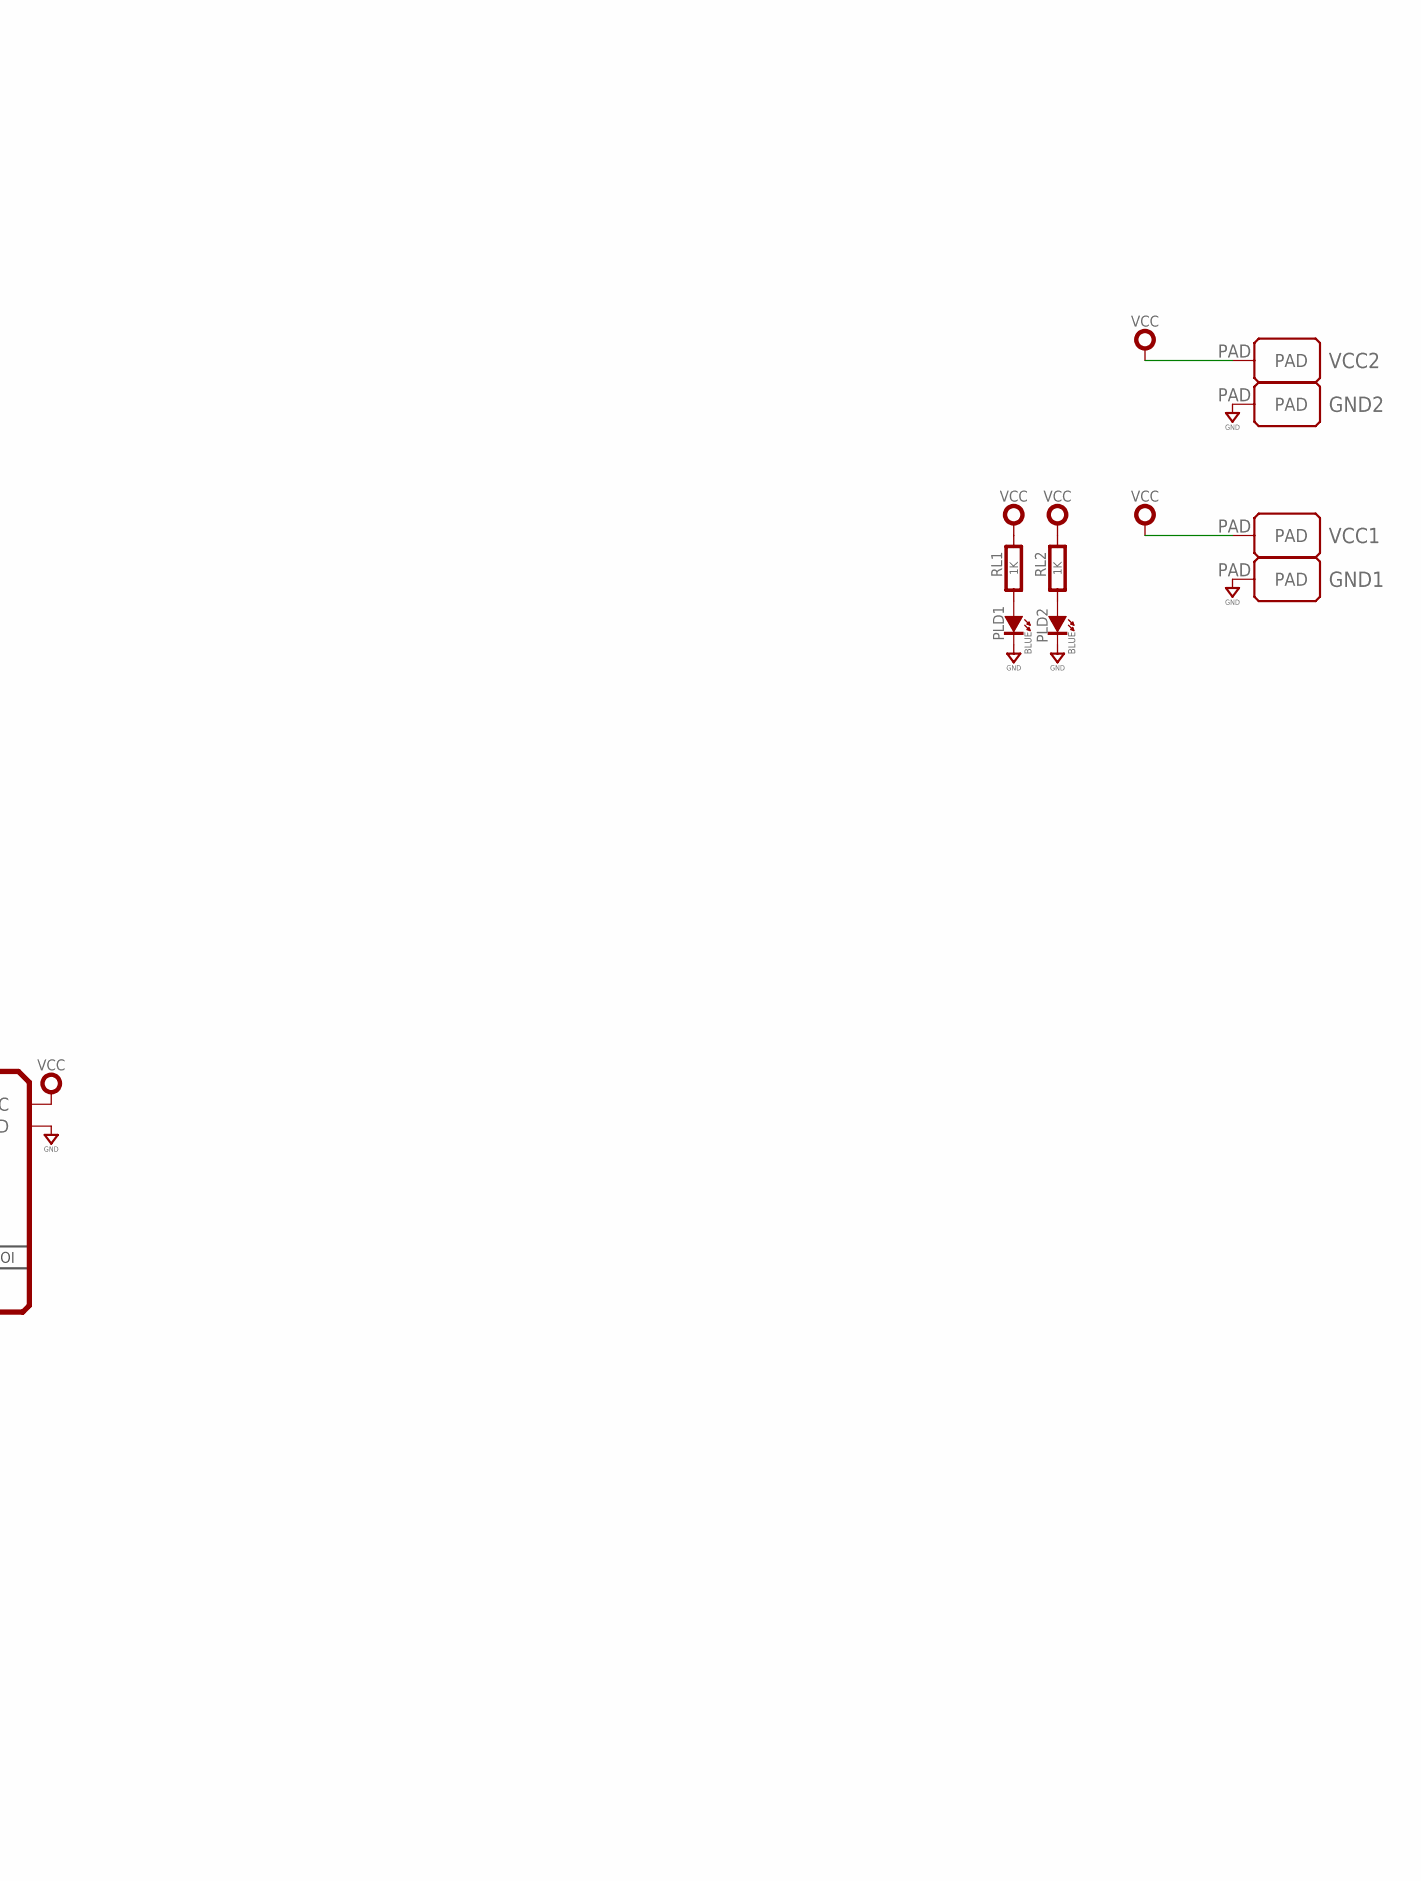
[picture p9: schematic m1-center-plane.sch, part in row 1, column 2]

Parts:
0, 1, 2, 3, 4, 5, 6, 7: BLUE; SMD_0603
A: M1-REG-A-BUS
ALU: M1-ALU-BUS
B: M1-REG-B-BUS
CLK: M1-CLOCK-BUS
CTL: M1-CONTROL-BUS
GND1, GND2: PADSMD-100X100; SMD-100X100
IR: M1-REG-INSTR-BUS; M1-REG-I-BUS
MAR: M1-MAR-BUS
OUT: M1-REG-OUTPUT-BUS
PC: M1-PROG-COUNTER-BUS; M1-PROGRAM-COUNTER-BUS
PLD1, PLD2: BLUE; SMD_0603
R0, R1, R2, R3, R4, R5, R6, R7: 1K; 0603-RES
R8, R9, R10, R11, R12, R13, R14, R15: 10K; 0603-RES
RAM: M1-RAM-BUS
RL1, RL2: 1K; 0603-RES
VCC1, VCC2: PADSMD-100X100; SMD-100X100

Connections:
!CLK: CLK.!CLK, CTL.!CLK
!CLR: CTL.!CLR, OUT.!CLR, PC.!CLR
BUS.0: A.BUS.0, ALU.BUS.0, B.BUS.0, IR.BUS.0, MAR.BUS.0, OUT.BUS.0 (0), PC.BUS.0, R0.2, R8.2, RAM.BUS.0
BUS.1: A.BUS.1, ALU.BUS.1, B.BUS.1, IR.BUS.1, MAR.BUS.1, OUT.BUS.1 (1), PC.BUS.1, R1.2, R9.2, RAM.BUS.1
BUS.2: A.BUS.2, ALU.BUS.2, B.BUS.2, IR.BUS.2, MAR.BUS.2, OUT.BUS.2 (2), PC.BUS.2, R2.2, R10.2, RAM.BUS.2
BUS.3: A.BUS.3, ALU.BUS.3, B.BUS.3, IR.BUS.3, MAR.BUS.3, OUT.BUS.3 (3), PC.BUS.3, R3.2, R11.2, RAM.BUS.3
BUS.4: A.BUS.4, ALU.BUS.4, B.BUS.4, IR.BUS.4, OUT.BUS.4 (4), R4.2, R12.2, RAM.BUS.4
BUS.5: A.BUS.5, ALU.BUS.5, B.BUS.5, IR.BUS.5, OUT.BUS.5 (5), R5.2, R13.2, RAM.BUS.5
BUS.6: A.BUS.6, ALU.BUS.6, B.BUS.6, IR.BUS.6, OUT.BUS.6 (6), R6.2, R14.2, RAM.BUS.6
BUS.7: A.BUS.7, ALU.BUS.7, B.BUS.7, IR.BUS.7, OUT.BUS.7 (7), R7.2, R15.2, RAM.BUS.7
CLK: A.CLK, ALU.CLK, B.CLK, CLK.CLK, IR.CLK, MAR.CLK, OUT.CLK, PC.CLK, RAM.CLK
CLR: A.CLR, ALU.CLR, B.CLR, CTL.CLR, IR.CLR, MAR.CLR
GND: 0.K (C), 1.K (C), 2.K (C), 3.K (C), 4.K (C), 5.K (C), 6.K (C), 7.K (C), A.GND, ALU.GND, B.GND, CLK.GND, CTL.GND, GND1.PAD, GND2.PAD, IR.GND, MAR.GND, OUT.GND, PC.GND, PLD1.K (C), PLD2.K (C), R8.1, R9.1, R10.1, R11.1, R12.1, R13.1, R14.1, R15.1, RAM.GND
unnamed: 0.A, R0.1
unnamed: 1.A, R1.1
unnamed: 2.A, R2.1
unnamed: 3.A, R3.1
unnamed: 4.A, R4.1
unnamed: 5.A, R5.1
unnamed: 6.A, R6.1
unnamed: 7.A, R7.1
unnamed: PLD2.A, RL2.1
unnamed: PLD1.A, RL1.1
VCC: A.VCC, ALU.VCC, B.VCC, CLK.VCC, CTL.VCC, IR.VCC, MAR.VCC, OUT.VCC, PC.VCC, RAM.VCC, RL1.2, RL2.2, VCC1.PAD, VCC2.PAD

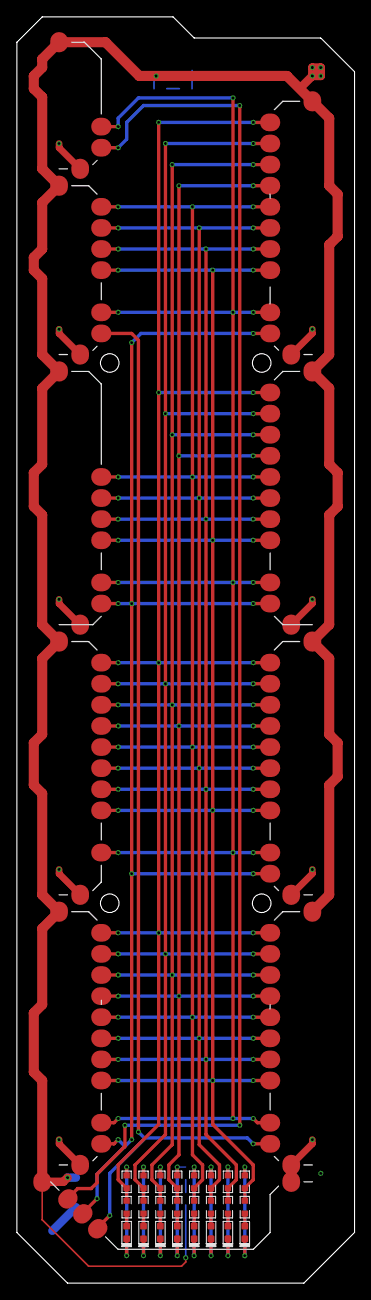
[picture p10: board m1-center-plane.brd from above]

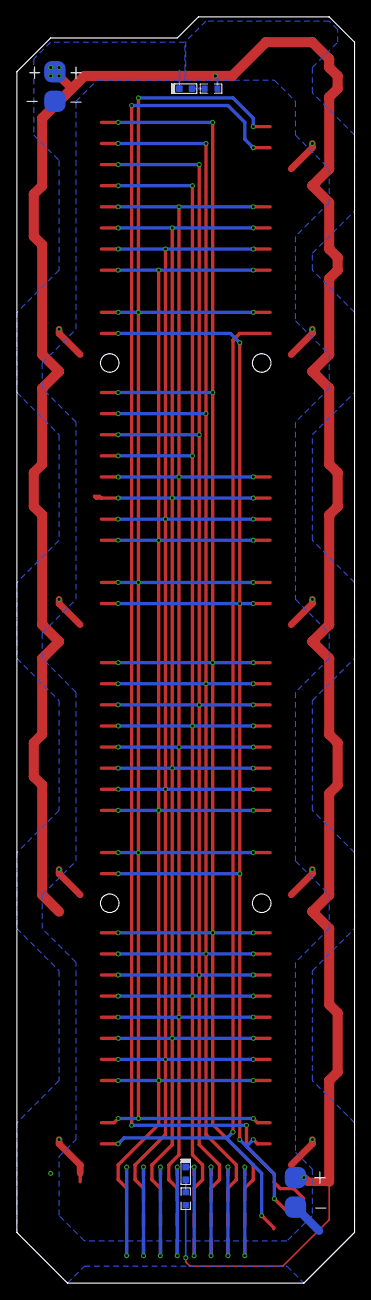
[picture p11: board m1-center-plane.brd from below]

Board: 2 copper layers, 40.0 x 150.0 mm, 42 parts (8 on the bottom side), 24 nets.

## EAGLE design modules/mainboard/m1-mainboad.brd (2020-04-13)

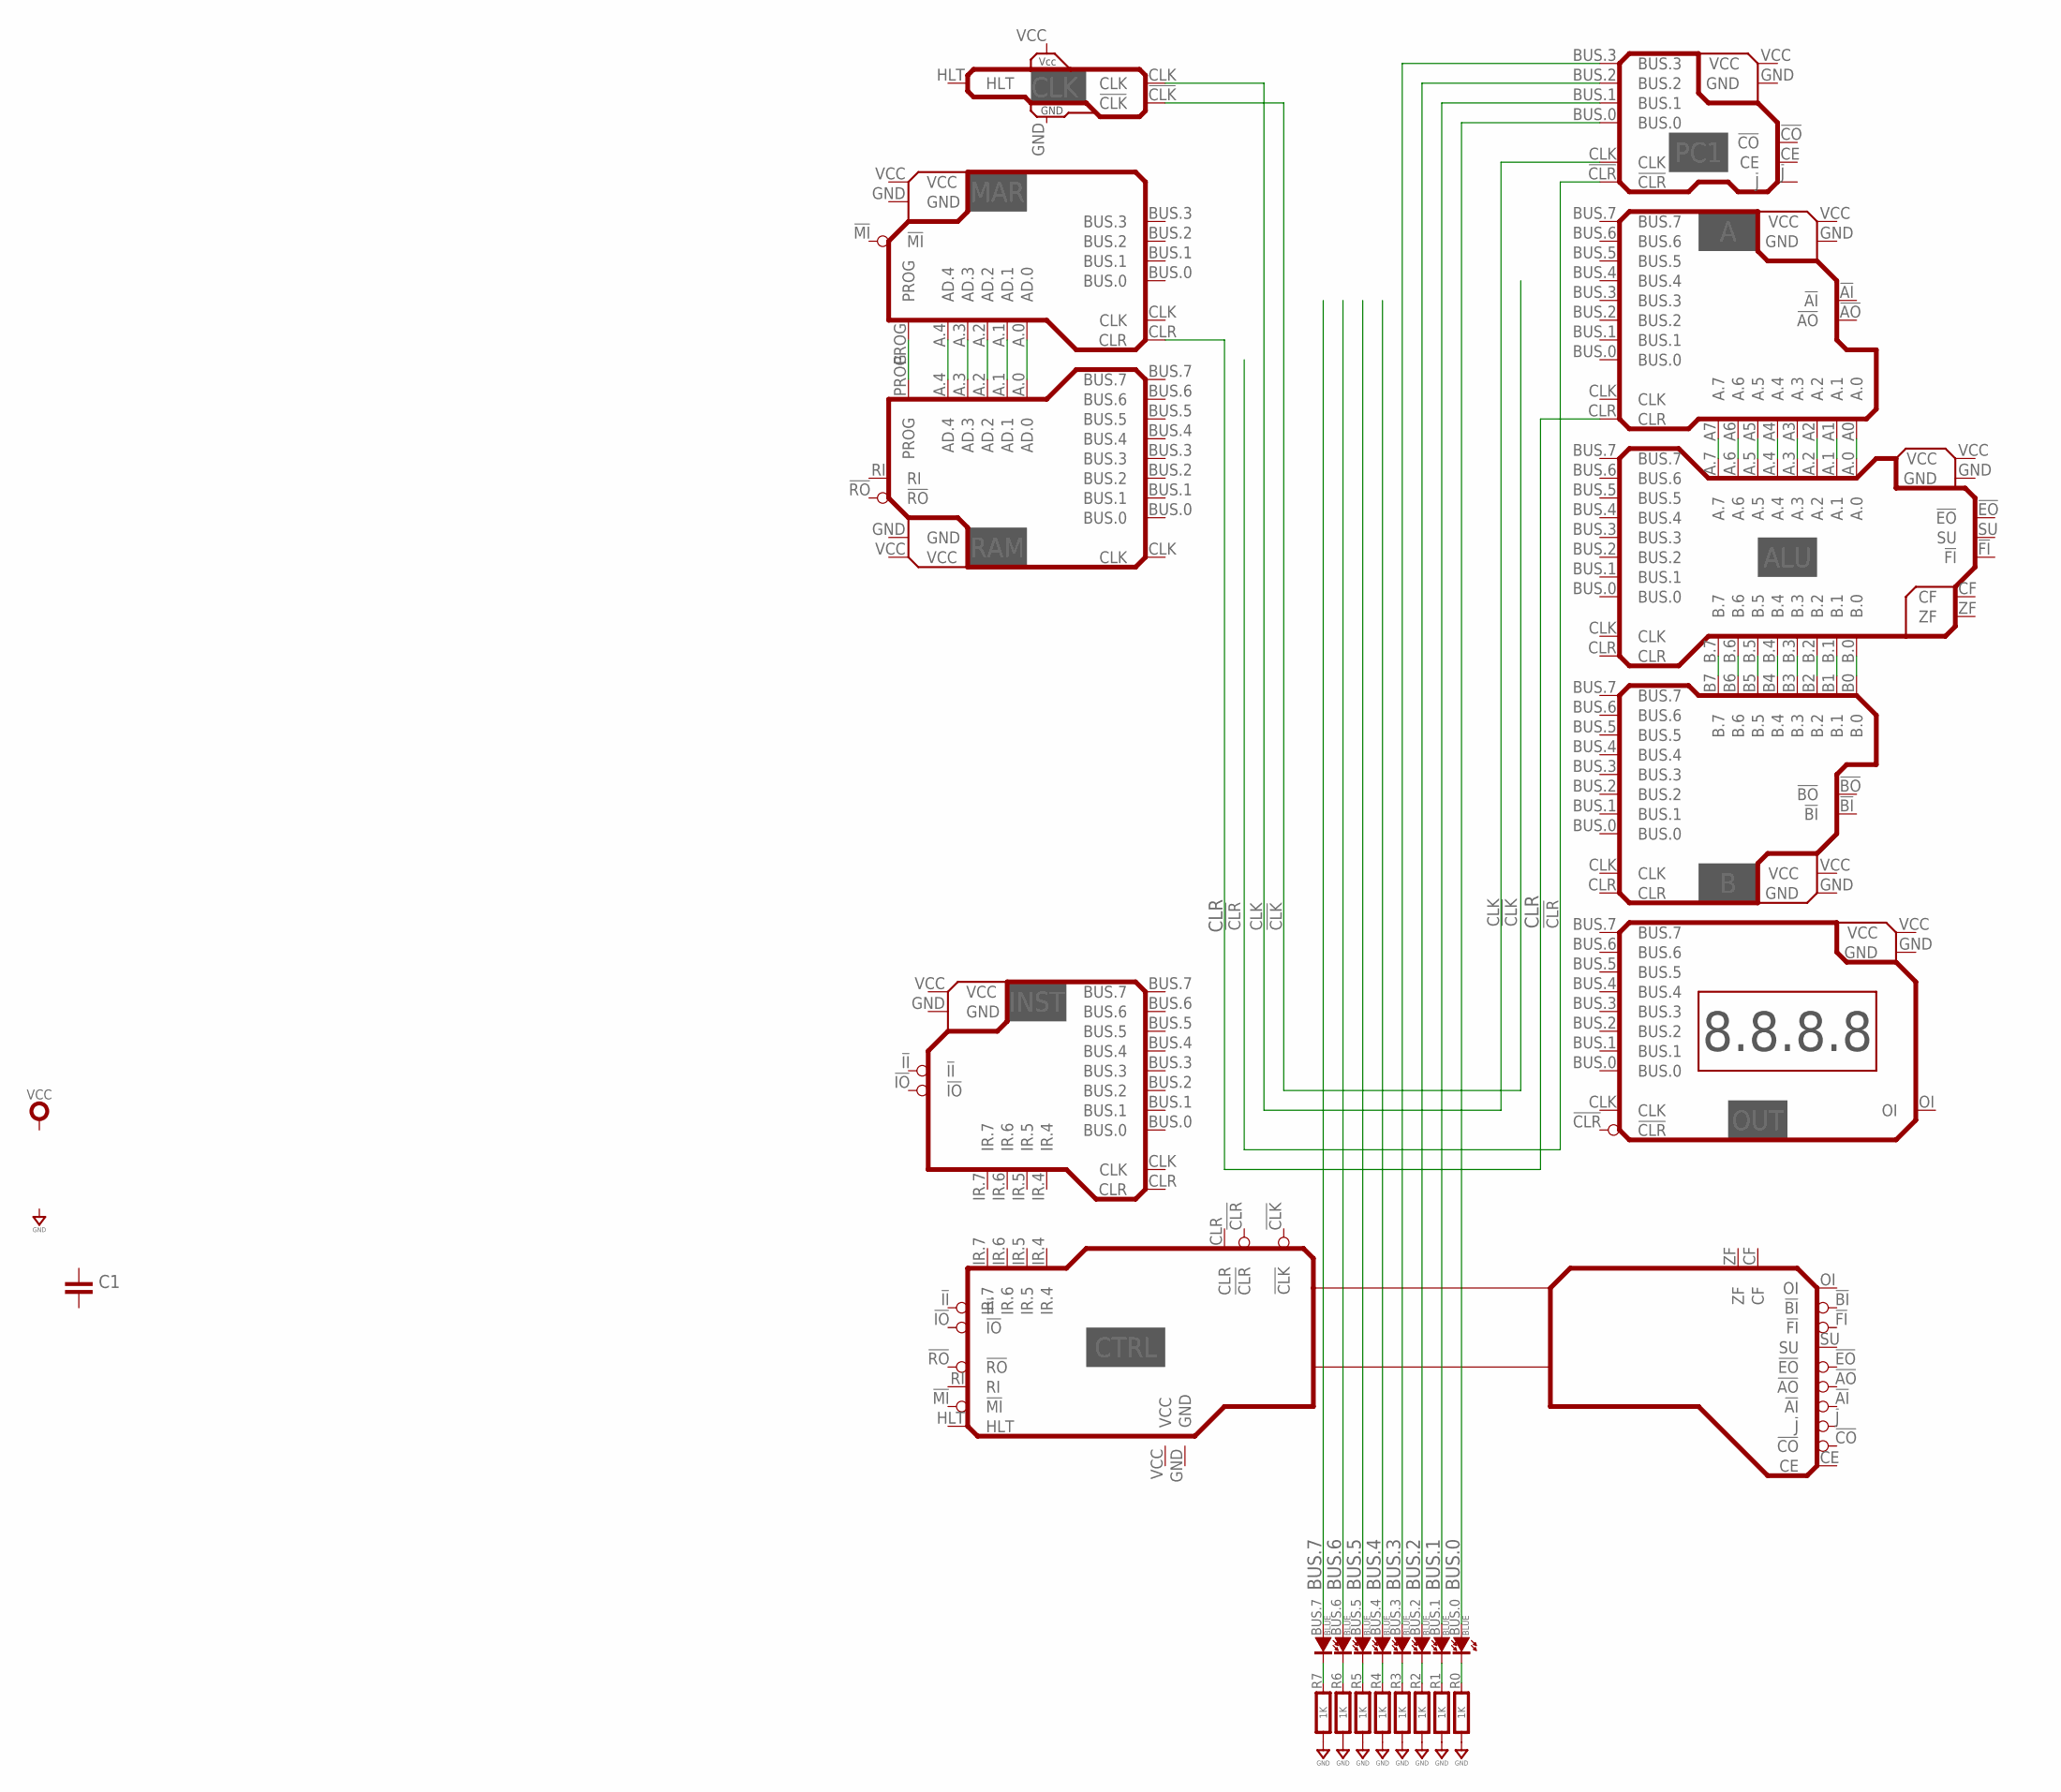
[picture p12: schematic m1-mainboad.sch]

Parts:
A: M1-REG-A-REV-A; M1-REG-A
ALU: M1-ALU-REV-A; M1-ALU
B: M1-REG-B-REV-A; M1-REG-B
BUS.0, BUS.1, BUS.2, BUS.3, BUS.4, BUS.5, BUS.6, BUS.7: BLUE; SMD_0603
C1: CAPACITOR0603; 0603-CAP
CLK: M1-CLOCKREV-A; M1-CLOCK
CTRL: M1-CONTROL-REV-A; M1-CONTROL
INST: M1-REG-INSTR-REV-A; M1-REG-I
MAR: M1-MAR-REV-A; M1-MAR
OUT: M1-REG-OUTPUT-REV-A; M1-REG-OUTPUT
PC1: M1-PROG-COUNTERREV-A; M1-PROGRAM-COUNTER
R0, R1, R2, R3, R4, R5, R6, R7: 1K; 0603-RES
RAM: M1-RAM-REV-A; M1-RAM

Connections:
!CLK: CLK.!CLK
!CLR: PC1.!CLR
BUS.0: BUS.0.A, PC1.BUS.0
BUS.1: BUS.1.A, PC1.BUS.1
BUS.2: BUS.2.A, PC1.BUS.2
BUS.3: BUS.3.A, PC1.BUS.3
BUS.4: BUS.4.A
BUS.5: BUS.5.A
BUS.6: BUS.6.A
BUS.7: BUS.7.A
CLK: CLK.CLK, PC1.CLK
CLR: A.CLR, MAR.CLR
GND: A.GND, ALU.GND, B.GND, CLK.GND, CTRL.GND, INST.GND, MAR.GND, OUT.GND, PC1.GND, R0.1, R1.1, R2.1, R3.1, R4.1, R5.1, R6.1, R7.1, RAM.GND
unnamed: BUS.0.K (C), R0.2
unnamed: BUS.1.K (C), R1.2
unnamed: BUS.2.K (C), R2.2
unnamed: BUS.3.K (C), R3.2
unnamed: BUS.4.K (C), R4.2
unnamed: BUS.5.K (C), R5.2
unnamed: BUS.6.K (C), R6.2
unnamed: BUS.7.K (C), R7.2
unnamed: A.A4 (A.4), ALU.A.4
unnamed: A.A5 (A.5), ALU.A.5
unnamed: A.A6 (A.6), ALU.A.6
unnamed: A.A7 (A.7), ALU.A.7
unnamed: A.A3 (A.3), ALU.A.3
unnamed: A.A2 (A.2), ALU.A.2
unnamed: A.A1 (A.1), ALU.A.1
unnamed: A.A0 (A.0), ALU.A.0
unnamed: ALU.B.4, B.B4 (B.4)
unnamed: ALU.B.5, B.B5 (B.5)
unnamed: ALU.B.6, B.B6 (B.6)
unnamed: ALU.B.7, B.B7 (B.7)
unnamed: ALU.B.3, B.B3 (B.3)
unnamed: ALU.B.2, B.B2 (B.2)
unnamed: ALU.B.1, B.B1 (B.1)
unnamed: ALU.B.0, B.B0 (B.0)
unnamed: MAR.A.0 (AD.0), RAM.A.0 (AD.0)
unnamed: MAR.A.1 (AD.1), RAM.A.1 (AD.1)
unnamed: MAR.A.2 (AD.2), RAM.A.2 (AD.2)
unnamed: MAR.A.3 (AD.3), RAM.A.3 (AD.3)
unnamed: MAR.A.4 (AD.4), RAM.A.4 (AD.4)
unnamed: MAR.PROG, RAM.PROG
VCC: A.VCC, ALU.VCC, B.VCC, CLK.VCC, CTRL.VCC, INST.VCC, MAR.VCC, OUT.VCC, PC1.VCC, RAM.VCC

Board: 2 copper layers, 27 parts (0 on the bottom side), 38 nets, no tracks yet.

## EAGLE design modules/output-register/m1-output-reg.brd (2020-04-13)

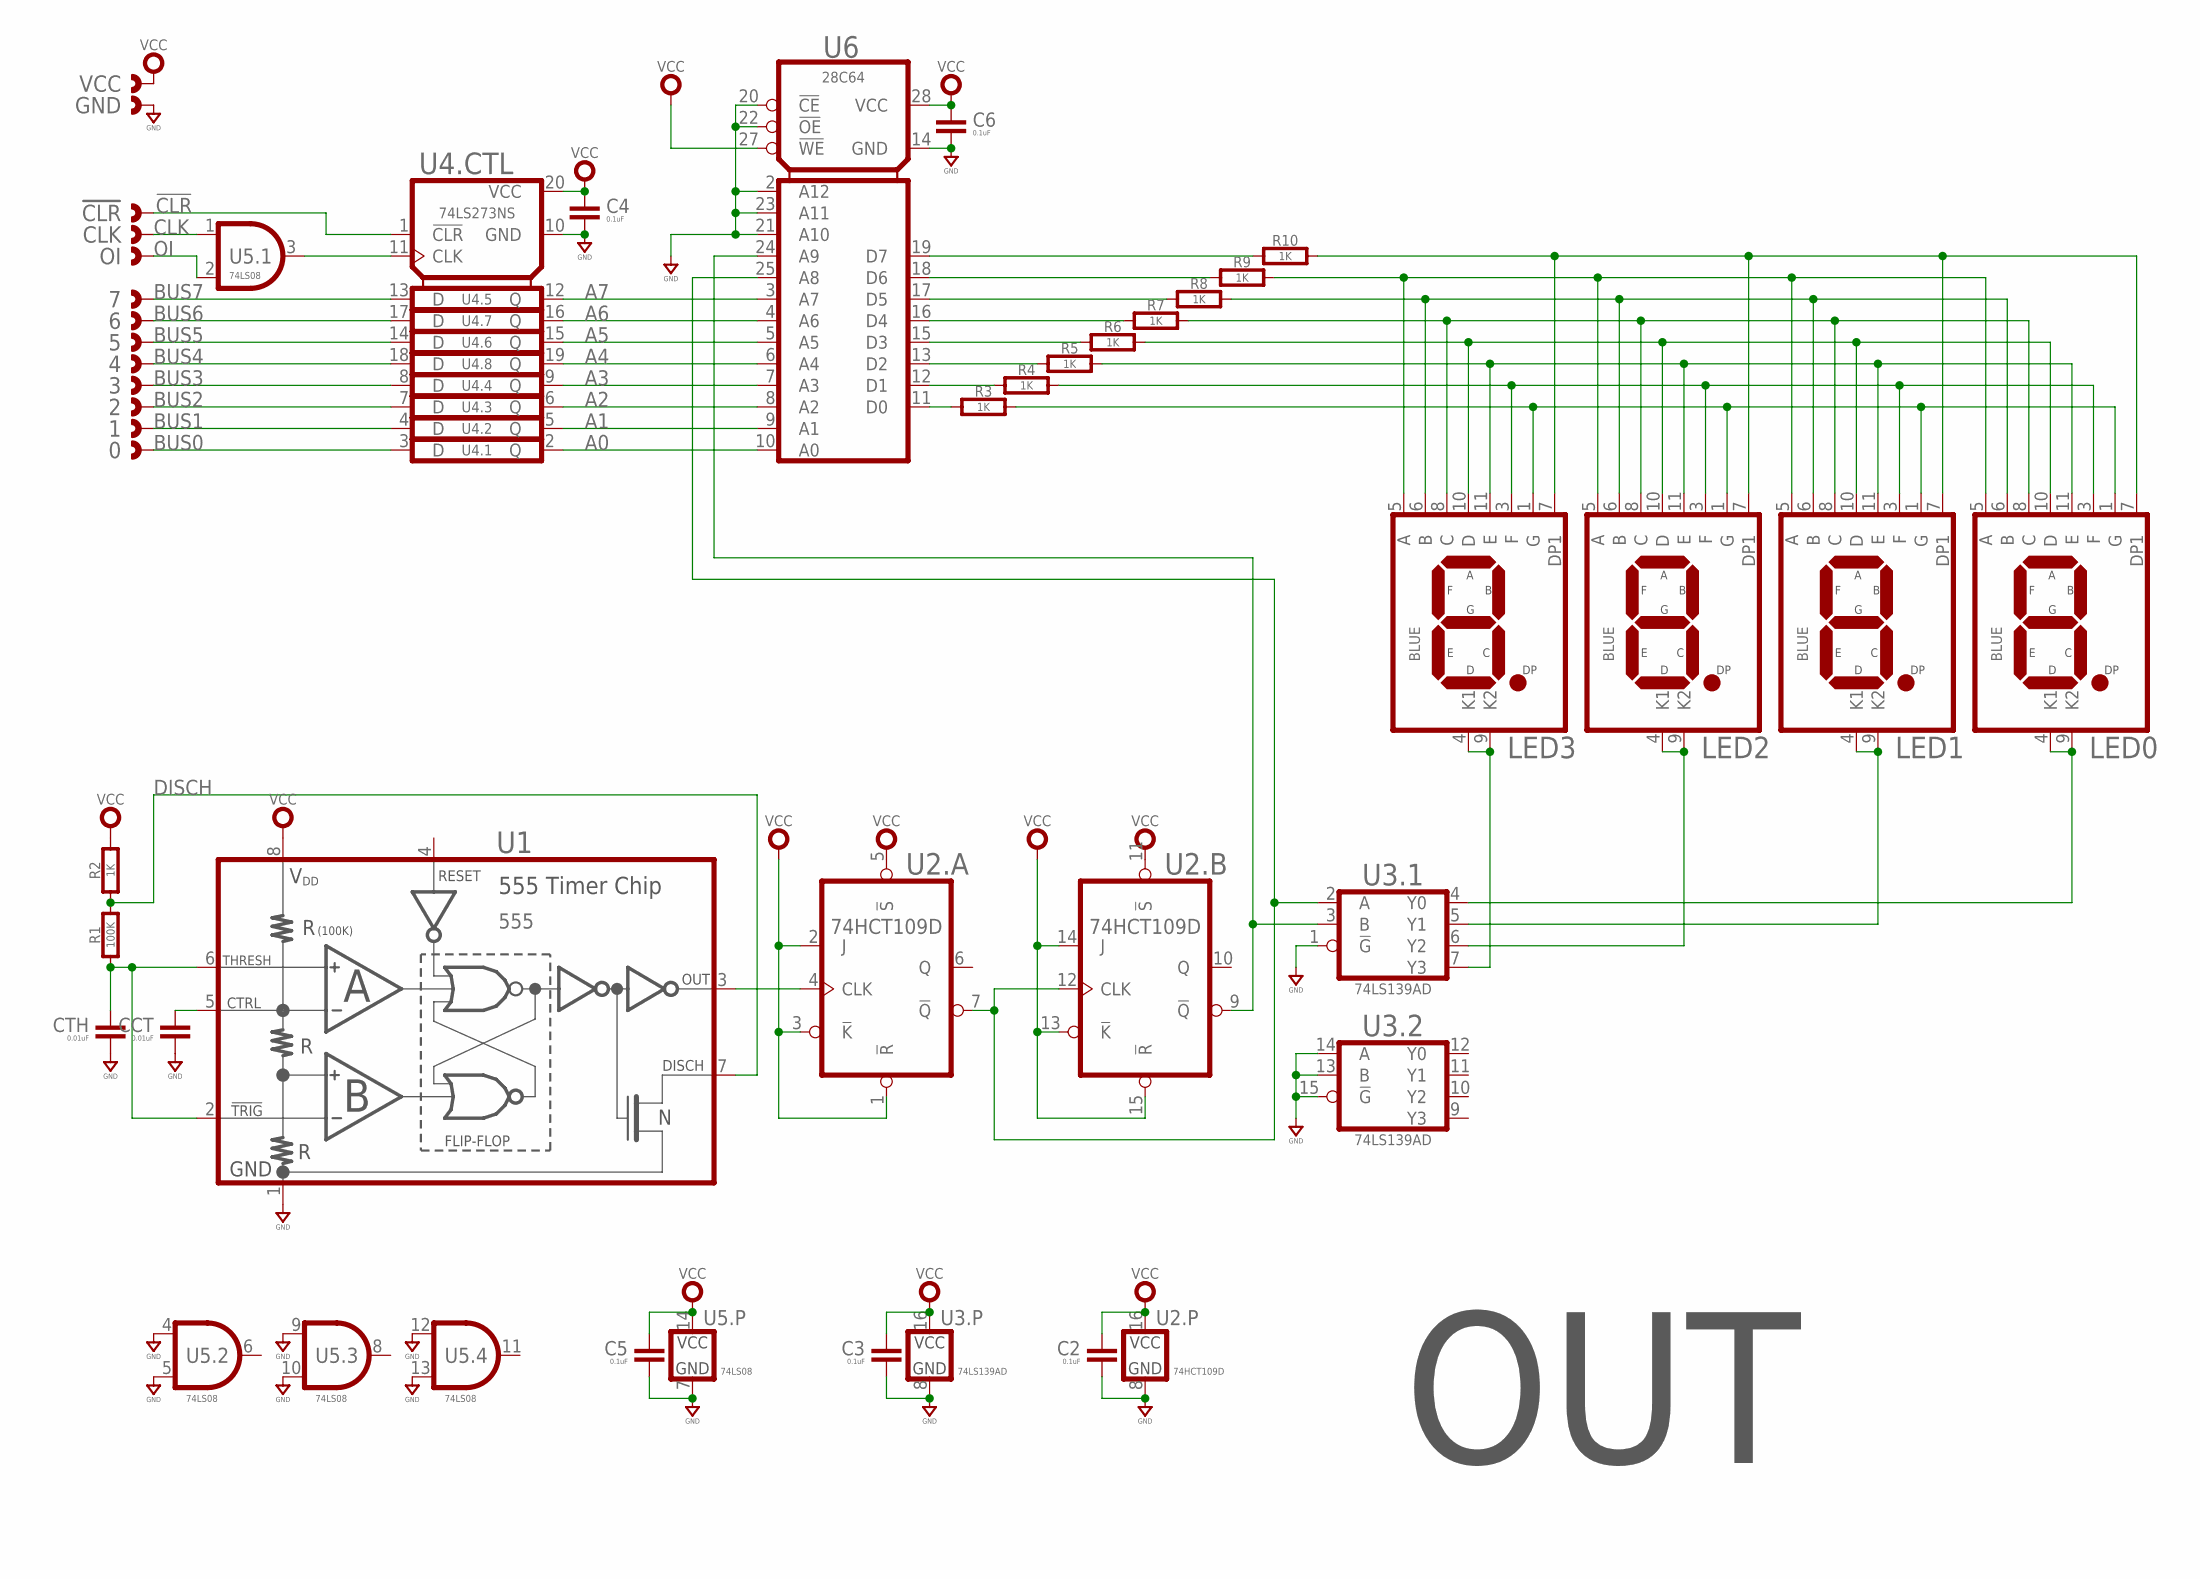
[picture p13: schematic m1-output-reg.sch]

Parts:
0, 1, 2, 3, 4, 5, 6, 7: CAST-01X1; CAST01-2.54MM
!CLR: CAST-01X1; CAST01-2.54MM
C2, C3, C4, C5, C6: 0.1uF; 0603-CAP
CCT: 0.01uF; 0603-CAP
CLK: CAST-01X1; CAST01-2.54MM
CTH: 0.01uF; 0603-CAP
GND: CAST-01X1; CAST01-2.54MM
LED0, LED1, LED2, LED3: BLUE; AVAGO-HDSM-281B-7SEG
OI: CAST-01X1; CAST01-2.54MM
R1: 100K; 0603-RES
R2, R3, R4, R5, R6, R7, R8, R9, R10: 1K; 0603-RES
U1: 555; SOP08
U2: 74HCT109D; SO16
U3: 74LS139AD; SO16
U4: 74LS273NS; SO20
U5: 74LS08; SOP14
U6: 28C64; SO28
VCC: CAST-01X1; CAST01-2.54MM

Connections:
!CLR: !CLR.1, U4.1 (!CLR)
A0: U4.2 (Q), U6.10 (A0)
A1: U4.5 (Q), U6.9 (A1)
A2: U4.6 (Q), U6.8 (A2)
A3: U4.9 (Q), U6.7 (A3)
A4: U4.19 (Q), U6.6 (A4)
A5: U4.15 (Q), U6.5 (A5)
A6: U4.16 (Q), U6.4 (A6)
A7: U4.12 (Q), U6.3 (A7)
BUS0: 0.1, U4.3 (D)
BUS1: 1.1, U4.4 (D)
BUS2: 2.1, U4.7 (D)
BUS3: 3.1, U4.8 (D)
BUS4: 4.1, U4.18 (D)
BUS5: 5.1, U4.14 (D)
BUS6: 6.1, U4.17 (D)
BUS7: 7.1, U4.13 (D)
CLK: CLK.1, U5.1 (A)
DISCH: R1.1, R2.1, U1.7 (DISCHARGE)
GND: C2.2, C3.2, C4.2, C5.2, C6.2, CCT.2, CTH.2, GND.1, U1.1 (GND), U2.8 (GND), U3.1 (!G), U3.8 (GND), U3.13 (B), U3.14 (A), U3.15 (!G), U4.10 (GND), U5.4 (A), U5.5 (B), U5.7 (GND), U5.9 (A), U5.10 (B), U5.12 (A), U5.13 (B), U6.2 (A12), U6.14 (GND), U6.20 (!CE), U6.21 (A10), U6.22 (!OE), U6.23 (A11)
unnamed: CTH.1, R1.2, U1.2 (TRIGGER#), U1.6 (THRESHOLD)
unnamed: CCT.1, U1.5 (CONTROL)
unnamed: U1.3 (OUTPUT), U2.4 (CLK)
unnamed: U2.9 (!Q), U3.3 (B), U6.24 (A9)
unnamed: U2.7 (!Q), U2.12 (CLK), U3.2 (A), U6.25 (A8)
unnamed: U4.11 (CLK), U5.3 (Y)
unnamed: R3.1, U6.11 (D0)
unnamed: R4.1, U6.12 (D1)
unnamed: R5.1, U6.13 (D2)
unnamed: R6.1, U6.15 (D3)
unnamed: R7.1, U6.16 (D4)
unnamed: R8.1, U6.17 (D5)
unnamed: R9.1, U6.18 (D6)
unnamed: R10.1, U6.19 (D7)
unnamed: LED0.7 (DP1), LED1.7 (DP1), LED2.7 (DP1), LED3.7 (DP1), R10.2
unnamed: LED0.5 (A), LED1.5 (A), LED2.5 (A), LED3.5 (A), R9.2
unnamed: LED0.6 (B), LED1.6 (B), LED2.6 (B), LED3.6 (B), R8.2
unnamed: LED0.4 (K1), LED0.9 (K2), U3.4 (Y0)
unnamed: LED0.8 (C), LED1.8 (C), LED2.8 (C), LED3.8 (C), R7.2
unnamed: LED0.10 (D), LED1.10 (D), LED2.10 (D), LED3.10 (D), R6.2
unnamed: LED0.11 (E), LED1.11 (E), LED2.11 (E), LED3.11 (E), R5.2
unnamed: LED0.3 (F), LED1.3 (F), LED2.3 (F), LED3.3 (F), R4.2
unnamed: LED0.1 (G), LED1.1 (G), LED2.1 (G), LED3.1 (G), R3.2
unnamed: LED3.4 (K1), LED3.9 (K2), U3.7 (Y3)
unnamed: LED2.4 (K1), LED2.9 (K2), U3.6 (Y2)
unnamed: LED1.4 (K1), LED1.9 (K2), U3.5 (Y1)
OI: OI.1, U5.2 (B)
VCC: C2.1, C3.1, C4.1, C5.1, C6.1, R2.2, U1.8 (VDD), U2.1 (!R), U2.2 (J), U2.3 (!K), U2.5 (!S), U2.11 (!S), U2.13 (!K), U2.14 (J), U2.15 (!R), U2.16 (VCC), U3.16 (VCC), U4.20 (VCC), U5.14 (VCC), U6.27 (!WE), U6.28 (VCC), VCC.1

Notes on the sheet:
OUT


Board: 2 copper layers, 60.0 x 32.0 mm, 40 parts (0 on the bottom side), 48 nets.

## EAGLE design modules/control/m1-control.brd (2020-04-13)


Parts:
!AI: CAST-01X1; CAST01-2.54MM
!AI!: BLUE; SMD_0603
!AO: CAST-01X1; CAST01-2.54MM
!AO!: BLUE; SMD_0603
!BI: CAST-01X1; CAST01-2.54MM
!BI!: BLUE; SMD_0603
!CLK: CAST-01X1; CAST01-2.54MM
!CLR: CAST-01X1; CAST01-2.54MM
!CO: CAST-01X1; CAST01-2.54MM
!CO!: BLUE; SMD_0603
!EO: CAST-01X1; CAST01-2.54MM
!EO!: BLUE; SMD_0603
!FI: CAST-01X1; CAST01-2.54MM
!FI!: BLUE; SMD_0603
!II: CAST-01X1; CAST01-2.54MM
!II!: BLUE; SMD_0603
!IO: CAST-01X1; CAST01-2.54MM
!IO!: BLUE; SMD_0603
!J: CAST-01X1; CAST01-2.54MM
!J!: BLUE; SMD_0603
!MI: CAST-01X1; CAST01-2.54MM
!MI!: BLUE; SMD_0603
!RO: CAST-01X1; CAST01-2.54MM
!RO!: BLUE; SMD_0603
!T0, !T1, !T2, !T3, !T4: BLUE; SMD_0603
C1, C2, C3, C4, C5, C6, C7: 0.1uF; 0603-CAP
CE: CAST-01X1; CAST01-2.54MM
CE.: BLUE; SMD_0603
CF: CAST-01X1; CAST01-2.54MM
CLEAR: MOM (OFF)-ON; SWITCH-0635-2P-SMD
CLR: CAST-01X1; CAST01-2.54MM
GND: CAST-01X1; CAST01-2.54MM
HLT: CAST-01X1; CAST01-2.54MM
HLT.: BLUE; SMD_0603
IR4, IR5, IR6, IR7: CAST-01X1; CAST01-2.54MM
MI.0, MI.1, MI.2: BLUE; SMD_0603
OI: CAST-01X1; CAST01-2.54MM
OI.: BLUE; SMD_0603
R1, R2, R3, R4, R5, R6, R7, R8, R9, R10, R11, R12, R13, R14, R15, R16, R17, R18, R19, R20, R21, R22, R23, R24, R25: 1K; 0603-RES
RI: CAST-01X1; CAST01-2.54MM
RI.: BLUE; SMD_0603
SU: CAST-01X1; CAST01-2.54MM
SU.: BLUE; SMD_0603
U1, U2: 28C64; SO28
U3: 74LS161AD; SO16
U4: 74LS00; SOP14
U5, U6: 74LS04; SOP14
U7: 74LS138; SO16
VCC: CAST-01X1; CAST01-2.54MM
ZF: CAST-01X1; CAST01-2.54MM

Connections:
!AI: !AI.1, U5.10 (Y)
!AO: !AO.1, U5.12 (Y)
!BI: !BI.1, U6.4 (Y)
!CLK: !CLK.1, U3.2 (CLK)
!CLR: !CLR.1, U4.5 (B), U4.8 (Y), U4.12 (B), U4.13 (A)
!CO: !CO.1, U6.6 (Y)
!EO: !EO.1, U6.2 (Y)
!FI: !FI.1, U6.10 (Y)
!II: !II.1, U5.8 (Y)
!IO: !IO.1, U5.6 (Y)
!J: !J.1, U6.8 (Y)
!MI: !MI.1, U5.2 (Y)
!MICLR: U3.1 (!CLR), U4.3 (Y)
!RO: !RO.1, U5.4 (Y)
!T0: R25.1, U7.15 (Y0)
!T1: R24.1, U7.14 (Y1)
!T2: R23.1, U7.13 (Y2)
!T3: R22.1, U7.12 (Y3)
!T4: R21.1, U7.11 (Y4)
AI: !AI!.A, U1.12 (D1), U5.11 (A)
AO: !AO!.A, U1.11 (D0), U5.13 (A)
BI: !BI!.A, U2.17 (D5), U6.3 (A)
CE: CE.1, CE..A, U2.15 (D3)
CF: CF.1, U1.25 (A8), U2.25 (A8)
CLR: CLR.1, U4.11 (Y)
CO: !CO!.A, U2.13 (D2), U6.5 (A)
EO: !EO!.A, U2.19 (D7), U6.1 (A)
FI: !FI!.A, U2.11 (D0), U6.11 (A)
GND: C1.2, C2.2, C3.2, C4.2, C5.2, C6.2, C7.2, GND.1, R1.1, R2.1, R3.1, R4.1, R5.1, R6.1, R7.1, R8.1, R9.1, R10.1, R11.1, R12.1, R13.1, R14.1, R15.1, R16.1, R17.1, R18.1, R19.1, R20.1, U1.2 (A12), U1.3 (A7), U1.14 (GND), U1.21 (A10), U1.23 (A11), U2.2 (A12), U2.14 (GND), U2.21 (A10), U2.23 (A11), U3.8 (GND), U4.7 (GND), U5.7 (GND), U6.7 (GND), U6.13 (A), U7.4 (!G!2A), U7.5 (!G!2B), U7.8 (GND)
HLT: HLT.1, HLT..A, U1.19 (D7)
II: !II!.A, U1.13 (D2), U5.9 (A)
IO: !IO!.A, U1.15 (D3), U5.5 (A)
IR4: IR4.1, U1.7 (A3), U2.7 (A3)
IR5: IR5.1, U1.6 (A4), U2.6 (A4)
IR6: IR6.1, U1.5 (A5), U2.5 (A5)
IR7: IR7.1, U1.4 (A6), U2.4 (A6)
J: !J!.A, U2.12 (D1), U6.9 (A)
MI: !MI!.A, U1.18 (D6), U5.1 (A)
MI.0: MI.0.A, U1.10 (A0), U2.10 (A0), U3.14 (QA), U7.1 (A)
MI.1: MI.1.A, U1.9 (A1), U2.9 (A1), U3.13 (QB), U7.2 (B)
MI.2: MI.2.A, U1.8 (A2), U2.8 (A2), U3.12 (QC), U7.3 (C)
unnamed: !FI!.K (C), R1.2
unnamed: !J!.K (C), R2.2
unnamed: !CO!.K (C), R3.2
unnamed: CE..K (C), R4.2
unnamed: OI..K (C), R5.2
unnamed: !BI!.K (C), R6.2
unnamed: R7.2, SU..K (C)
unnamed: !EO!.K (C), R8.2
unnamed: !AO!.K (C), R9.2
unnamed: !AI!.K (C), R10.2
unnamed: !II!.K (C), R11.2
unnamed: !IO!.K (C), R12.2
unnamed: !RO!.K (C), R13.2
unnamed: R14.2, RI..K (C)
unnamed: !MI!.K (C), R15.2
unnamed: HLT..K (C), R16.2
unnamed: U4.1 (A), U4.2 (B), U4.6 (Y)
unnamed: U4.4 (A), U7.10 (Y5)
unnamed: MI.2.K (C), R18.2
unnamed: CLEAR.1, R17.2, U4.9 (B), U4.10 (A)
unnamed: MI.1.K (C), R19.2
unnamed: MI.0.K (C), R20.2
unnamed: !T4.K (C), R21.2
unnamed: !T3.K (C), R22.2
unnamed: !T2.K (C), R23.2
unnamed: !T1.K (C), R24.2
unnamed: !T0.K (C), R25.2
OI: OI.1, OI..A, U2.16 (D4)
RI: RI.1, RI..A, U1.17 (D5)
RO: !RO!.A, U1.16 (D4), U5.3 (A)
SU: SU.1, SU..A, U2.18 (D6)
VCC: !T0.A, !T1.A, !T2.A, !T3.A, !T4.A, C1.1, C2.1, C3.1, C4.1, C5.1, C6.1, C7.1, CLEAR.2, U1.27 (!WE), U1.28 (VCC), U2.3 (A7), U2.27 (!WE), U2.28 (VCC), U3.7 (ENP), U3.9 (!LOAD), U3.10 (ENT), U3.16 (VCC), U4.14 (VCC), U5.14 (VCC), U6.14 (VCC), U7.6 (G1), U7.16 (VCC), VCC.1
ZF: U1.24 (A9), U2.24 (A9), ZF.1

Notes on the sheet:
CTL


Board: 2 copper layers, 135.0 x 23.5 mm, 91 parts (0 on the bottom side), 74 nets.

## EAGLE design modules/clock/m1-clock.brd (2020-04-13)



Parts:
!CLK: CAST-01X1; CAST01-2.54MM
.CLK.: BLUE; SMD_0603
C1, C3, C5: 0.01uF; 0603-CAP
C2: 1.0uF; 0603-CAP
C4: 0.1uF; 0603-CAP
CLK: CAST-01X1; CAST01-2.54MM
CU4, CU5: 0.01uF; 0603-CAP
F: 1M; TRIM_BOURNS_TC33X
GND: CAST-01X1; CAST01-2.54MM
HALT: CAST-01X1; CAST01-2.54MM
MODE: SLIDE-SPDTJS102011JCQN; CK_JS102011JCQN
R1, R2, R3, R5, R6, R7: 1K; 0603-RES
R4: 1M; 0603-RES
STEP: MOM (OFF)-ON; SWITCH-0635-2P-SMD
U1, U2, U3: 555; SOP08
U4: 74LS08; SOP14
U5: 74LS32; SOP14
U6: 74LS04; SOP14
VCC: CAST-01X1; CAST01-2.54MM

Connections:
!CLK: !CLK.1, U6.8 (Y)
CLK: .CLK..A, CLK.1, U4.6 (Y), U6.9 (A)
GND: C1.2, C2.2, C3.2, C4.2, C5.2, CU4.2, CU5.2, GND.1, MODE.2, R7.2, STEP.1, U1.1 (GND), U2.1 (GND), U2.6 (THRESHOLD), U3.1 (GND), U4.1 (A), U4.2 (B), U4.7 (GND), U5.1 (A), U5.2 (B), U5.4 (A), U5.5 (B), U5.7 (GND), U5.9 (A), U5.10 (B), U6.3 (A), U6.5 (A), U6.7 (GND), U6.13 (A)
HALT: HALT.1, U6.11 (A)
unnamed: C1.1, U1.5 (CONTROL)
unnamed: C2.1, F.T (3), U1.2 (TRIGGER#), U1.6 (THRESHOLD)
unnamed: U1.3 (OUTPUT), U4.12 (A)
unnamed: R1.1, R2.2, U1.7 (DISCHARGE)
unnamed: F.C (2), R2.1
unnamed: C3.1, U3.5 (CONTROL)
unnamed: R3.2, STEP.2, U3.2 (TRIGGER#)
unnamed: U3.3 (OUTPUT), U4.10 (B)
unnamed: MODE.3, R5.1, U2.4 (RESET#)
unnamed: C4.1, R4.2, U3.6 (THRESHOLD), U3.7 (DISCHARGE)
unnamed: MODE.1, R6.1, U2.2 (TRIGGER#)
unnamed: C5.1, U2.5 (CONTROL)
unnamed: U4.9 (A), U6.2 (Y)
unnamed: U2.3 (OUTPUT), U4.13 (B), U6.1 (A)
unnamed: U4.11 (Y), U5.12 (A)
unnamed: U4.8 (Y), U5.13 (B)
unnamed: U4.4 (A), U5.11 (Y)
unnamed: U4.5 (B), U6.10 (Y)
unnamed: .CLK..K (C), R7.1
VCC: CU4.1, CU5.1, R1.2, R3.1, R4.1, R5.2, R6.2, U1.4 (RESET#), U1.8 (VDD), U2.8 (VDD), U3.4 (RESET#), U3.8 (VDD), U4.14 (VCC), U5.14 (VCC), U6.14 (VCC), VCC.1


Board: 2 copper layers, 45.0 x 23.0 mm, 29 parts (0 on the bottom side), 24 nets.

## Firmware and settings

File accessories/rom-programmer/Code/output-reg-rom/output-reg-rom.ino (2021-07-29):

/*

   Programs the ROM for the output register.

   Solstice StarFire module modified version:
   From original Ben Eater code (using Arduino and a different circuit).
   https://github.com/beneater/eeprom-programmer/blob/master/multiplexed-display/multiplexed-display.ino


   @author Maehem


   Pins:

    - !MCE  A0        OUTPUT
    - !MOE  A1        OUTPUT
    - ADR9  A2        OUTPUT
    - ADR8  A3        OUTPUT
    - !WE   A4        OUTPUT
    - !PASS/FAIL  A5  OUTPUT  (Set as input to turn off)
    - !PROG 13        OUTPUT
    - !SOE  12        OUTPUT
    - !RST  11        OUTPUT
    - LAT   10        OUTPUT
    - SHFT   9        OUTPUT
    - SADDR  8        OUTPUT

    - D[0:7]  0:7
*/

#include <Adafruit_NeoPixel.h>
#ifdef __AVR__
#include <avr/power.h> // Required for 16 MHz Adafruit Trinket
#endif
#define LED_PIN    SCK
#define LED_COUNT 16
Adafruit_NeoPixel strip(LED_COUNT, LED_PIN, NEO_GRB + NEO_KHZ800);
#define RED strip.Color(255,   0,   0)
#define GRN strip.Color(  0, 255,   0)
#define YEL strip.Color(255, 255,   0)

#define MCE_ A0
#define MOE_ A1
#define ADR10 12
#define ADR9 A2
#define ADR8 A3
#define WRITE_EN  A4
#define FAIL A5

#define SADDR  8
#define SHFT_CLK  9
#define SHFT_LAT  10
#define RST_  11
//#define SOE_  12
#define PROG_ 13

// Bit patterns for the digits 0..9
byte digits[] = { 0x7e, 0x30, 0x6d, 0x79, 0x33, 0x5b, 0x5f, 0x70, 0x7f, 0x7b };


void setup() {
  Serial.begin(115200);
  while (!Serial);
  Serial.println("ROM Programmer");

  strip.begin();           // INITIALIZE NeoPixel strip object (REQUIRED)
  strip.show();            // Turn OFF all pixels ASAP
  strip.setBrightness(10); // Set BRIGHTNESS to about 1/5 (max = 255)

  pinMode(MCE_, OUTPUT);
  pinMode(MOE_, OUTPUT);
  pinMode(WRITE_EN, OUTPUT);
  pinMode(SADDR, OUTPUT);
  pinMode(SHFT_LAT, OUTPUT);
  pinMode(SHFT_CLK, OUTPUT);
  pinMode(RST_, OUTPUT);
  //pinMode(SOE_, OUTPUT);
  pinMode(PROG_, OUTPUT);
  pinMode(ADR10, OUTPUT);
  pinMode(ADR9, OUTPUT);
  pinMode(ADR8, OUTPUT);

  pinMode(FAIL, OUTPUT);
  digitalWrite(FAIL, 1);

  //strip.setPixelColor(0, GRN);         //  Set pixel's color (in RAM)
  //strip.show();

  // PROM state
  digitalWrite(MCE_, HIGH);
  digitalWrite(MOE_, HIGH);
  digitalWrite(MCE_, HIGH);
  digitalWrite(WRITE_EN, HIGH);

  // Shift Register State
  //digitalWrite(SOE_, HIGH);
  digitalWrite(RST_, HIGH);
  digitalWrite(SHFT_CLK, HIGH);
  digitalWrite(SHFT_LAT, HIGH);


  Serial.println("Programming ones place");
  for (int value = 0; value <= 255; value++) {
    writeEEPROM(value, digits[value % 10]);
  }
  strip.setPixelColor(0, RED);         //  Set pixel's color (in RAM)
  strip.show();


  strip.setPixelColor(1, YEL);         //  Set pixel's color (in RAM)
  strip.show();
  Serial.println("Programming tens place");
  for (int value = 0; value <= 255; value++) {
    writeEEPROM(value + 0x0100, digits[(value / 10) % 10]);
  }
  strip.setPixelColor(1, RED);         //  Set pixel's color (in RAM)
  strip.show();

  strip.setPixelColor(2, YEL);         //  Set pixel's color (in RAM)
  strip.show();
  Serial.println("Programming hundreds place");
  for (int value = 0; value <= 255; value++) {
    writeEEPROM(value + 0x0200, digits[(value / 100) % 10]);
  }
  strip.setPixelColor(2, RED);         //  Set pixel's color (in RAM)
  strip.show();

  strip.setPixelColor(3, YEL);         //  Set pixel's color (in RAM)
  strip.show();
  Serial.println("Programming sign");
  for (int value = 0; value <= 255; value ++) {
    writeEEPROM(value + 0x0300, 0);
  }
  strip.setPixelColor(3, RED);         //  Set pixel's color (in RAM)
  strip.show();

  strip.setPixelColor(4, YEL);         //  Set pixel's color (in RAM)
  strip.show();



  Serial.println("Programming ones place (twos complement)");
  for (int value = -128; value <= 127; value += 1) {
    writeEEPROM((byte)value + 0x400, digits[abs(value) % 10]);
  }
  strip.setPixelColor(4, RED);         //  Set pixel's color (in RAM)
  strip.show();

  strip.setPixelColor(5, YEL);         //  Set pixel's color (in RAM)
  strip.show();
  Serial.println("Programming tens place (twos complement)");
  for (int value = -128; value <= 127; value += 1) {
    writeEEPROM((byte)value + 0x500, digits[abs(value / 10) % 10]);
  }
  strip.setPixelColor(5, RED);         //  Set pixel's color (in RAM)
  strip.show();

  strip.setPixelColor(6, YEL);         //  Set pixel's color (in RAM)
  strip.show();
  Serial.println("Programming hundreds place (twos complement)");
  for (int value = -128; value <= 127; value += 1) {
    writeEEPROM((byte)value + 0x600, digits[abs(value / 100) % 10]);
  }
  strip.setPixelColor(6, RED);         //  Set pixel's color (in RAM)
  strip.show();

  strip.setPixelColor(7, YEL);         //  Set pixel's color (in RAM)
  strip.show();
  Serial.println("Programming sign (twos complement)");
  for (int value = -128; value <= 127; value += 1) {
    if (value < 0) {
      writeEEPROM((byte)value + 0x700, 0x01);
    } else {
      writeEEPROM((byte)value + 0x700, 0);
    }
  }
  strip.setPixelColor(7, RED);         //  Set pixel's color (in RAM)
  strip.show();

  delay(2000);

  boolean pass;

  pass = true;
  // Verify
  Serial.println("Verifying ones place");
  strip.setPixelColor(15,  YEL);
  for (int value = 0; value <= 255; value++) {
    if ( readEEPROM(value) == digits[value % 10] ) {
      Serial.println("  #");
    } else {
      Serial.println("  .");
      pass = false;
    }
  }
  strip.setPixelColor(15, pass ? GRN : RED);     //  Set pixel's color (in RAM)
  strip.show();

  Serial.println("Verifying tens place");
  pass = true;
  strip.setPixelColor(14,  YEL);
  for (int value = 0; value <= 255; value++) {
    if ( readEEPROM(value | 0x100) == digits[(value / 10) % 10] ) {
      Serial.println("  #");
    } else {
      Serial.println("  .");
      pass = false;
    }
  }
  strip.setPixelColor(14,  pass ? GRN : RED);     //  Set pixel's color (in RAM)
  strip.show();

  Serial.println("Verifying hundreds place");
  pass = true;
  strip.setPixelColor(13,  YEL);
  for (int value = 0; value <= 255; value++) {
    if ( readEEPROM(value | 0x200) == digits[(value / 100) % 10] ) {
      Serial.println("  #");
    } else {
      Serial.println("  .");
      pass = false;
    }
  }
  strip.setPixelColor(13,  pass ? GRN : RED);     //  Set pixel's color (in RAM)
  strip.show();

  Serial.println("Verifying sign");
  pass = true;
  strip.setPixelColor(12,  YEL);
  for (int value = 0; value <= 255; value++) {
    if ( readEEPROM(value | 0x300 ) == 0 ) {
      Serial.println("  #");
    } else {
      Serial.println("  .");
      pass = false;
    }
  }
  strip.setPixelColor(12,  pass ? GRN : RED);     //  Set pixel's color (in RAM)
  strip.show();





  Serial.println("Verifying ones place (twos complement)");
  strip.setPixelColor(11,  YEL);
  pass=true;
  for (int value = -128; value <= 127; value += 1) {
    if ( readEEPROM((byte)value + 0x400) == digits[abs(value) % 10] ) {
      Serial.println("  #");
    } else {
      Serial.println("  .");
      pass = false;
    }
  }
  strip.setPixelColor(11, pass ? GRN : RED);     //  Set pixel's color (in RAM)
  strip.show();

  Serial.println("Verifying tens place (twos complement)");
  strip.setPixelColor(10,  YEL);
  pass=true;
  for (int value = -128; value <= 127; value += 1) {
    if ( readEEPROM((byte)value + 0x500) == digits[abs(value / 10) % 10] ) {
      Serial.println("  #");
    } else {
      Serial.println("  .");
      pass = false;
    }
  }
  strip.setPixelColor(10, pass ? GRN : RED);     //  Set pixel's color (in RAM)
  strip.show();

  Serial.println("Verifying hundreds place (twos complement)");
  strip.setPixelColor(9,  YEL);
  pass=true;
  for (int value = -128; value <= 127; value += 1) {
    if ( readEEPROM((byte)value + 0x600) == digits[abs(value / 100) % 10] ) {
      Serial.println("  #");
    } else {
      Serial.println("  .");
      pass = false;
    }
  }
  strip.setPixelColor(9, pass ? GRN : RED);     //  Set pixel's color (in RAM)
  strip.show();

  Serial.println("Verifying sign place (twos complement)");
  strip.setPixelColor(8,  YEL);
  pass=true;
  for (int value = -128; value <= 127; value += 1) {
    int expected;
    if (value < 0) {
      expected = 0x01;
    } else {
      expected = 0;
    }
   
    if ( readEEPROM((byte)value + 0x700) == expected ) {
      Serial.println("  #");
    } else {
      Serial.println("  .");
      pass = false;
    }
  }
  strip.setPixelColor(8, pass ? GRN : RED);     //  Set pixel's color (in RAM)
  strip.show();



  Serial.println("...done!");

}

void loop() {
  // put your main code here, to run repeatedly:

}

/**
   Output the address bits and outputEnable signal using shift registers.
*/
void setAddress(int address, bool outputEnable) {
  // Set address bits 8 and 9
  digitalWrite(ADR10, address >> 10 & 0x01 );
  digitalWrite(ADR9, address >> 9 & 0x01 );
  digitalWrite(ADR8, address >> 8 & 0x01 );

  shiftOut(SADDR, SHFT_CLK, MSBFIRST, address & 0xFF);

  digitalWrite(SHFT_LAT, LOW);
  digitalWrite(SHFT_LAT, HIGH);
  digitalWrite(SHFT_LAT, LOW);

}

/*
   Write a byte to the EEPROM at the specified address.
*/
void writeEEPROM(int address, byte data) {
  Serial.print("Write addr:");
  Serial.print(address, HEX);
  Serial.print(" ==> ");
  if ( data < 0b10000000 ) {
    Serial.print("0");
  }
  if ( data < 0b01000000 ) {
    Serial.print("0");
  }
  if ( data < 0b00100000 ) {
    Serial.print("0");
  }
  if ( data < 0b00010000 ) {
    Serial.print("0");
  }
  if ( data < 0b00001000 ) {
    Serial.print("0");
  }
  if ( data < 0b00000100 ) {
    Serial.print("0");
  }
  if ( data < 0b00000010 ) {
    Serial.print("0");
  }

  Serial.println( data, BIN );

  setAddress(address, /*outputEnable*/ false);
  //digitalWrite(SOE_, LOW);

  for (int pin = 0; pin <= 7; pin++) {
    pinMode(pin, OUTPUT);
  }

  for (int pin = 0; pin <= 7; pin ++) {
    digitalWrite(pin, data & 0x01);
    data = data >> 1;
  }

  digitalWrite(MCE_, LOW);
  digitalWrite(WRITE_EN, LOW);

  delayMicroseconds(1);
  digitalWrite(WRITE_EN, HIGH);
  delayMicroseconds(2);
  digitalWrite(MCE_, HIGH);
  delayMicroseconds(1);

//  digitalWrite(SOE_, HIGH);

  for (int pin = 0; pin <= 7; pin++) {
    pinMode(pin, INPUT);
  }

  delay(10);
}

byte readEEPROM(int address) {
  Serial.print("Read addr:");
  Serial.print(address, HEX);
  //  Serial.print(" :: ");
  //  Serial.println(data, BIN );

  setAddress(address, /*outputEnable*/ false);
  //digitalWrite(SOE_, LOW);

  for (int pin = 0; pin <= 7; pin++) {
    pinMode(pin, INPUT);
  }


  digitalWrite(MCE_, LOW);
  digitalWrite(MOE_, LOW);

  delayMicroseconds(1);

  byte data = 0;
  for (int pin = 0; pin <= 7; pin ++) {
    data |= digitalRead(pin) << pin;
  }

  digitalWrite(MOE_, HIGH);
  delayMicroseconds(2);
  digitalWrite(MCE_, HIGH);
  delayMicroseconds(1);

//  digitalWrite(SOE_, HIGH);


  Serial.print(" ==> ");
  if ( data < 0b10000000 ) {
    Serial.print("0");
  }
  if ( data < 0b01000000 ) {
    Serial.print("0");
  }
  if ( data < 0b00100000 ) {
    Serial.print("0");
  }
  if ( data < 0b00010000 ) {
    Serial.print("0");
  }
  if ( data < 0b00001000 ) {
    Serial.print("0");
  }
  if ( data < 0b00000100 ) {
    Serial.print("0");
  }
  if ( data < 0b00000010 ) {
    Serial.print("0");
  }

  Serial.print( data, BIN );
  delay(10);

  return data;
}
//// prints 8-bit data in hex
//void PrintHex83(uint8_t *data, uint8_t length)  {
//  char tmp[length * 2 + 1];
//  byte first ;
//  int j = 0;
//  for (uint8_t i = 0; i < length; i++)
//  {
//    first = (data[i] >> 4) | 48;
//    if (first > 57) tmp[j] = first + (byte)39;
//    else tmp[j] = first ;
//    j++;
//
//    first = (data[i] & 0x0F) | 48;
//    if (first > 57) tmp[j] = first + (byte)39;
//    else tmp[j] = first;
//    j++;
//  }
//  tmp[length * 2] = 0;
//  Serial.print(tmp);
//}

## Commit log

2020-04-13 Progress checkin
    Centerplane, Output . register and clock board fabricted.
    Output board has REDLINE notes.
    [BOMs.ods, m1-alu.brd, m1-alu.sch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]
2021-07-29 Various updates
    [BOMs.ods, m1-data-register-a.brd, m1-data-register-a.sch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]
